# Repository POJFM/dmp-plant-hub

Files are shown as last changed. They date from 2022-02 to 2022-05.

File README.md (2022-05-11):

# 🌱 PlantHub

Ultra advanced smart irrigation system.

<div style="text-align: center;">
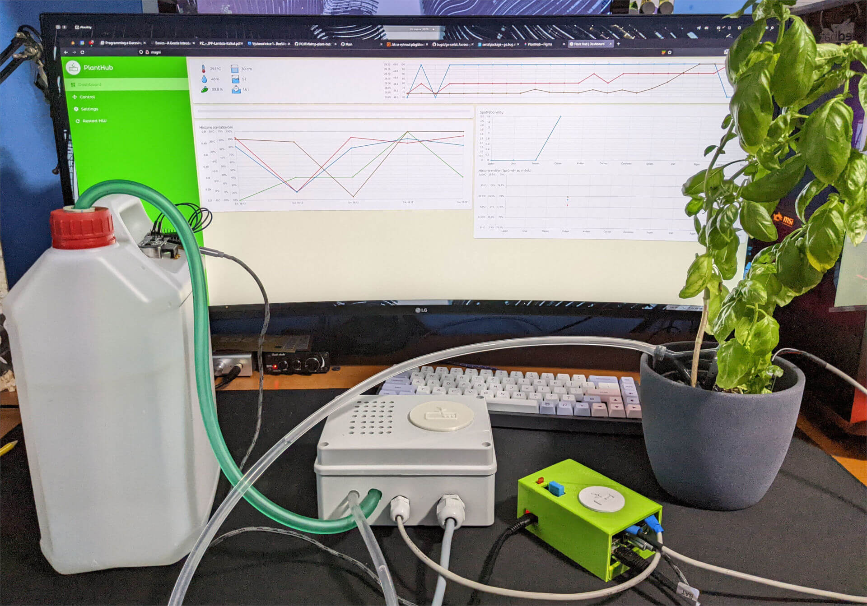
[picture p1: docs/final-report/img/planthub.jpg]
planthub
  
</div>

## 🍔 Tech stack

### 🖥️ Server and main app

- Chad GoLang
- Postgres DB :5420
- communication with HW modules/sensors via GPIO
- GraphQL API for DB data
- REST API for live data from sensors

### 🌿 Web app (client)

- React
- Tailwind
- Material UI
- [Design on Figma](https://www.figma.com/file/7gMKRPDOrkKOT5GKmOmfsu/PlantHub?node-id=0%3A1)

## 🔧 Setup on RPi

clone the repository

```bash
git clone git@github.com:POJFM/dmp-plant-hub.git
cd dmp-plant-hub
```

create server and docker `.env` files

```bash
# server .env
cp server/.env.example server/.env
# docker .env
cp docker.env.example docker.env
```

let docker do its thing

```bash
docker-compose up -d
```

## 📦 Build docker images for arm

create client `.env` file

```bash
cp client/.env.example client/.env
```

setup docker

```bash
# create bob the builder
docker buildx create --name bob
# switch to bob
docker buildx use bob
docker buildx inspect --bootstrap
docker login
docker buildx
```

build and push images or run `scripts/build-docker.sh`

```bash
# client image
docker buildx build --platform linux/amd64,linux/arm64,linux/arm/v7 -t tassilobalbo/planthub-client --push client/.
# server image
docker buildx build --platform linux/arm64,linux/arm/v7 -t tassilobalbo/planthub-server --push server/.
```

## 🏠 Setup local subnet

- Install dhcp package:
  `yay -Syu dhcpcd`
- Configure subnet in `/etc/dhcpd.conf`:

```
subnet 192.168.0.0 netmask 255.255.255.224 {
  range 192.168.0.10 192.168.0.20;
}
```

- Add your network card to subnet
  `sudo ip addr add 192.168.0.1/24 dev enp3s0`
- Restart dhcp daemon
  `systemctl restart dhcpd4`

## 📄 Compile XeLaTeX to pdf

1. Add `XeLaTeX` config in vscode

```
    "latex-workshop.latex.recipe.default": "latexmk (xelatex)",
    "latex-workshop.latex.tools": [
        {
            "name": "xelatexmk",
            "command": "latexmk",
            "args": [
                "-xelatex",
                "-outdir=out",
                "final-report.tex"
            ]
        },
        {
            "name": "latexmk",
            "command": "latexmk",
            "args": [
                "-xelatex",
                "-synctex=1",
                "-interaction=nonstopmode",
                "-file-line-error",
                "%DOC%"
            ]
        }
    ],
    "latex-workshop.latex.recipes": [
        {
            "name": "latexmk (xelatex)",
            "tools": [
                "xelatexmk"
            ]
        }
    ],
```

2. Download `Calibri.ttf` and put it in `~/.fonts`
3. Compile with `latexmk -xelatex -outdir=final-report ./final-report/final-report.tex`

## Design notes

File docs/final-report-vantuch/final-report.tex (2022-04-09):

\documentclass[12pt,a4paper]{article}
\usepackage[utf8]{inputenc}
\usepackage[sfdefault]{ClearSans}
\usepackage[T1]{fontenc}
\usepackage[left=35mm,right=20mm,top=25mm,bottom=25mm]{geometry}
\usepackage[czech]{babel}
\usepackage{titling}
\usepackage{graphicx}
\usepackage{caption}
\usepackage[list=true]{subcaption}
\usepackage{acronym}
\usepackage{setspace}
\usepackage{indentfirst}
\usepackage{hyperref}
\usepackage{listings}
\usepackage{tabularx}

\newcommand{\subtitle}[1]{%
	\posttitle{%
		\par\end{center}
		\begin{center}\large#1\end{center}
		\vskip0.5em}%
}

\newcommand*\wildcard[2][5cm]{\vspace*{2cm}\parbox{#1}{\centering\hrulefill\par#2\par}}

\graphicspath{ {./img/} }

%\onehalfspacing
\setlength{\parindent}{2em}
\setlength{\parskip}{0.1em}
\linespread{1.5}

\title{PlantHub}
\subtitle{MATURITNÍ ZKOUŠKA }
\author{Filip Sikora, Jakub Vantuch}
\date{}

\begin{document}

\begin{titlepage}
	\noindent
	%\vspace{0.1cm} \\
	\begin{center}
		\vspace*{0.2cm}
		\Huge\textbf{MATURITNÍ ZKOUŠKA}
		\vspace*{1cm} \\
		\large \emph{PRAKTICKÁ ZKOUŠKA Z ODBORNÝCH PŘEDMĚTŮ}
		\vspace*{1cm} \\
		\Large Téma č. 4 \\
		\vspace*{1cm}
		\Large Zavlažovací systém PlantHub \\
		\vspace*{1.3cm}
		%\vfill
		\normalsize
	\end{center}
	\begin{tabularx}{\textwidth}{l@{\hskip 0.5cm}XXl}
		Obor vzdělání:        & \multicolumn{3}{c}{\textbf{18 – 20 –
		M/01
		Informační technologie}}
		\\[10pt]
		Třída:                & \textbf{4. IT}
		                      &
		Autor práce:          & \textbf{Jakub Vantuch}
		\\[10pt]
		Školní rok:           & \textbf{2021/22}
		                      &
		Vedoucí učitel práce: &
		\textbf{Ing. Jiří Sumbal}
		\vspace*{2cm}
	\end{tabularx}
	„Prohlašuji, že jsem tuto práci vypracoval samostatně a použil jsem
	literárních
	pramenů a informací, které cituji a uvádím v seznamu použité literatury
	a
	dalších zdrojů informací.“

	\begin{tabularx}{\textwidth}{l@{\hskip 0.5cm}XXl}
		\\[10pt]
		V Frýdku-Místku, dne:             & \textbf{\dotfill}
		                                  &
		\textbf{\dotfill} & podpis
	\end{tabularx}
\end{titlepage}

\clearpage

\section*{Anotace}

PlantHub je automatický zavlažovací systém s \ac{WUI}.
Jádrem našeho systému je mikropočítač \ac{RPi} s procesorovou architekturou
\ac{ARM},
\ac{GPIO} a možností připojení pomocí ethernetu.
Vybrali jsme si jej, protože kombinuje malou velikost a vyšší výpočetní sílu
než Arduino. Musí totiž zvládnout řídit všechny senzory, ukládat data do
databáze a zároveň hostuje i samotnou webovou aplikaci. Systém PlantHub dále
získává informace o teplotě, vlhkosti a tlaku vzduchu a promítá je ve svém
\ac{WUI}. Ve stejné chvíli naměřená data ukládá do databáze v periodě 4
hodin. Jelikož voda časem z nádrže dojde systém PlantHub snímá stav hladiny
vody v nádrži a včas upozorní, že je třeba doplnit vodu.

\section*{Klíčová slova}

zavlažování; automatizace; statistika; živě; RaspberryPi; uživatelské rozhraní

\clearpage

\tableofcontents

\clearpage

\section{Úvod}

Mým cílem je návrh, sestavení a naprogramování automatického zavlažovacího
systému s názvem PlantHub. Systém se skládá z řídící jednotky (stanice),
senzorů, čerpadla, nádrže a \ac{WUI}. Tato stanice pravidelně snímá data ze
senzorů
měřících
teplotu a vlhkost vzduchu, vlhkost půdy a stav hladiny v nádrži, z té pak
stanice přečerpává vodu pomocí čerpadla spouštěného tranzistorem. Naměřená
data
se posílají živě pomocí \ac{REST} \ac{API} prostřednictvím
protokolu HTTP do \ac{WUI}. Samostně se poté v periodě čtyř hodin ukládají do
PostgreSQL databáze běžící v docker
containeru. Docker container si můžeme představit jako jednodušší a lépe
škálovatelnou verzi
virtualizace. Uložená data se vykreslí do
statistik
změn teploty a vlhkosti vzduchu, vlhkosti půdy a počtů zavlažování v časovém
rozsahu zobrazitelných v dashboardu \ac{WUI}. Pro načtení historických dat z
databáze
používáme \ac{GraphQL} \ac{API}, jelikož nabízí šetrnější přístup k datům,
vybráním pouze
těch záznamů z tabulky, které opravdu využíváme. V případě nedostupnosti
serveru by se ve \ac{WUI} měla pořád načítat živě naměřená data z \ac{REST}
\ac{API}. Přístup
k naměřeným datům a
\ac{WUI} má pouze
uživatel lokální
sítě, do které je planthub připojen pomocí ethernet kabelu. Pro správnou funkci
stanice je tedy zapotřebí router s přístupem k internetu a DHCP serverem.

Ve \ac{WUI} hostovaném na naší stanici, a sestavém pomocí javascriptového
frameworku
React.js, CSS frameworku
Tailwind a programovacího jazyku Typescript, který je supersetem javascriptu,
podporujícím volitelné statické typování, má uživatel
možnost zobrazení statistik jak živě naměřených dat tak dat historických v
nastavitelných grafech dashboardu. \ac{WUI} také nabízí manuální kontrolu nad
čerpadlem s časovačem začátku zavlažování a restartem hlavního programu.
Nastavitelné je jak \ac{WUI} tak i samotné faktory zavlažování jako je limit
vlhkosti
půdy, doba zavlažování nebo limit hladiny vody.

Jednotlivé součásti a moduly stanice jsme vybrali podle finanční dostupnosti a
adekvátních technických
požadavků na přesnost měření.
Zapojení těchto modulů do obvodu jsme prvně provedli ve webové aplikaci
EasyEDA, která nabízí jednoduché prostředky pro návrh technických
schémat. Tento obvod jsme poté v testovací verzi postavili na nepájivém
poli a ve finální verzi navrhli a objednali vlastní \ac{PCB}. Pro ochranu naší
stanice jsme v open-source programu FreeCad navrhli model krytu, který jsme
následně vytiskli na 3D tiskárně. Vymstila se nám však nepřesnost rozměrů krytu
a při vkládání stanice do krytu se nám podařilo zlomit SD kartu s operačním
systémem, daty a nasazenými programy. Po reinstalaci operačního systému jsme
opravili rozměry vytvořeného modelu krytu a
vytiskli kryt podruhé, tentokrát ve správných rozměrech.

Hlavní program jsme v prvotní verzi psali ve vysokoúrovňovém programovacím
jazyce Python, od kterého jsme nakonec upustili kvůli vysokým technickým
nárokům. Naše rozhodnutí nás nakonec dovedlo k jazyku
Go vytvořeného Googlem a určeného pro concurrency, rychlou kompilaci i průběh
programu, backend webových aplikací a mnoho
další funkcionality. Tento jazyk se nám zalíbil natolik že jsme se v něm
rozhodli
udělat jak \ac{API},
databázové funkce tak i hlavní program. Program je rozdělen na několik sekvencí
z toho hlavní jsou měřící sekvence kde se každou sekundu provádí měření dat ze
senzorů a následné odesílání na \ac{REST} \ac{API} webové aplikace a channely
vytvořené
pro komunikaci mezi go rutinama a sekvence controlleru, která pomocí snímání
dat z databáze určuje jestli se jedná o první spuštění PlantHubu, a podle toho
určí jestli se spustí incializační sekvence nebo sekvence zavlažování.

\clearpage

\section{Seznam zkratek a pojmů}

\begin{acronym}
	\acro{WUI}{Webové uživatelské rozhraní}
	\acro{API}{Application programming interface}
	\acro{REST}{Representaion programming interface}
	\acro{GraphQL}{Graph query languge}
	\acro{PCB}{Printed circuit board}
	\acro{RPi}{Raspberry Pi}
	\acro{CPU}{Central Processing Unit}
	\acro{ARM}{Advanced RISC Machines}
	\acro{GPIO}{General-purpose input/output}
	\acro{ADC}{Analogově digitální převodník}
	\acro{DHT11}{Digital humidity temperature v.11}
	\acro{HC-SR04}{Ultrasonický senzor vzdálenosti}
	\acro{LED}{Light Emitting Diode}
	\acro{SAR}{Successive-approximation}
	\acro{PETG}{Polyethylene terephthalate glycol filament}
	\acro{LSB}{Least significant bit}
	\acro{CLR}{Common Language Runtime}
	\acro{JVM}{Java virtual machine}
\end{acronym}

\clearpage

\section{Hardware}

Potřebujeme vyvinout vhodné pouzdro pro naše Raspberry, abychom ochránili
citlivé elektronické součástky a ve stejné chvíli měli možnost jednoduše
vyjmout stanici z krytu. Budeme ho tisknout na 3D tiskárně pevným \ac{PETG}
filamentem. K
zavlažování je potřeba postavit i nádrž na vodu, ze které bude naše čerpadlo
přečerpávat vodu k zavlažování, proto jsme se rozhodli pro nádobu s co
nejvetším objemem a postavili ji z upraveného 5L soudku.

\subsection{Senzory}

\subsubsection{Senzor teploty a vlhkosti vzduchu DHT11}

Senzor \ac{DHT11} se skládá z jednotky pro měření teploty, jednotky pro měření
vlhkosti a převodníku.

Teplotu měří senzor thermistorem. Thermistor je keramický polovodič, který
zmenšuje svou rezistivitu, když se okolní teplota zvýší.

Vlhkost měří senzor na základě rezistivity substrátu umístěného mezi dvěma
elektrodami. Tento substrát zachytává vlhkost a vytváří tak vodivé prostředí

\subsubsection{Senzor vlhkosti půdy}

Jedná se o kapacitní senzor, ten se skládá ze dvou vodivých desek a převodníku.
Čidlo funguje na způsob kapacitoru avšak jeho kapacita je ovlivněna vlhkostí,
která ovlivňuje dielektrikum mezi dvěma deskami.

\subsubsection{Analogově digitální převodník MCP3008}

\ac{RPi} má v rámci \ac{GPIO} pouze digitální vstupy, protože je ale senzor
vlhkosti půdy
analogový museli jsme použít \ac{ADC}. Přemapujeme tedy analogový
signál
do
osmi různých digitálních hodnot, kterým se také říká 3bitové rozlišení, to
definuje tu nejmenší hodnotu změny, který převodník dokáže rozlišit, této
hodnotě se říká \ac{LSB}. \ac{ADC} poté pomocí \ac{SAR}
definuje adresu v binárním podání srozumitelným pro digitální vstup.

% \begin{figure}[h]
% 	\centering
% 	\includegraphics[width=8cm]{sar_adc.png}
% 	\caption{\ac{SAR}}
% \end{figure}

\subsubsection{Ultrasonický senzor HC-SR04}

\ac{HC-SR04} vydává zvukové vibrace na vysoké frekvenci, neslyšitelné pro
lidské
ucho. Poté čeká, až se zvuk odrazí zpět, a vypočítá vzdálenost na základě času
měřeného od vysílání zvukové vlny k zpětnému přijmutí

Všechny naměřené údaje jsou v převodníku senzoru přepočítány na jednotky dané
veličiny a odeslány analogovým signálem do řídící jednotky.

\subsubsection{Čerpadlo}

Naše zvolené ponorné mini čerpadlo eses se skládá z DC motoru, na němž je
upevněna centrifuga pro
čerpání vody a vlastního pouzdra, z kterého vede otvor pro napojení odtokové
hadičky. Čerpadlo je připojeno na zdroj napětí 5V a zem.

\subsubsection{Tranzistor 2N2222}

Protože samotný signální pin neposkytuje dostatečné napětí pro chod čerpadla
ovládáme jej tranzistorem 2N2222. Tento tranzistor je bipolární
Negative-Positive-Negative tranzistor, to znamená že jeho polarita je nastavená
tak aby na kolektoru přijímal pozitivní napětí. Díky našemu vyměnitelnému
připojení modulů je
možné čerpadlo vyměnit a přívodný kabel používat jako spouštěč čerpadla
jakéhokoliv výkonu a nároků na zdroj.

\subsection{Architektura ARM}

\ac{ARM} je nejnovější \ac{CPU} architektura. Využívají ji všechny moderní
chytré
telefony, zařízení s operačním systémem Android i Apple produkty. Dnes už mají
\ac{ARM} procesory zařízení s Windows nebo MacOS.\@

% \ac{ARM} je založen na RISC (Reduced Instruction Set Computing), tyto procesory jsou designované na 

\clearpage

\section{Návrh obvodu a plošného spoje}

Testovací verzi našeho obvodu jsme postavili na nepájivém kontaktním poli,
které jsme používali pouze v testovací verzi. Jakmile jsme měli vše plně
odzkoušeno a plně otestováno přešli jsme na profesionálnější řešení.
Což tedy v druhé fázi znamenalo sestrojit a nechat vytisknout náš vlastní obvod
přepracovaného schématu \ac{PCB} a vytisknutého společnosti JLCPCB na naše
vlastní
náklady.

\begin{figure}[h]
	\centering
	\begin{subfigure}[b]{0.4\linewidth}
		
		\caption{Diagram \ac{PCB}}
	\end{subfigure}
	\begin{subfigure}[b]{0.4\linewidth}
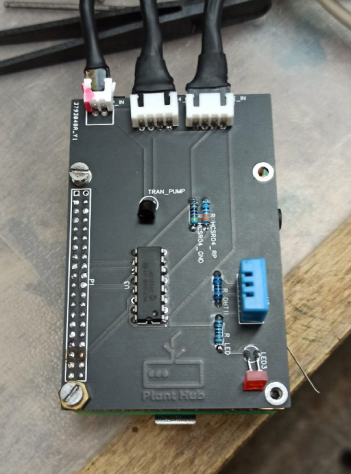
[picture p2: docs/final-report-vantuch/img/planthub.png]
		
		\caption{PlantHub \ac{PCB} se senzory}
	\end{subfigure}
	\caption{}
\end{figure}

\clearpage

\section{Fyzická realizace}

% předělat na fotku celého planthubu

\begin{figure}[h]
	\centering
	
	\caption{Fyzická realizace}
\end{figure}

\clearpage

\section{Hlavní program}

\subsection{Postup práce}

Náš hlavní program pro zavlažování a komunikaci s databází a \ac{WUI}
jsme začali psát ve vysokoúrovňovém programovacím jazyce Python. Od toho jsme
ale nakonec upustili kvůli horší výkonu, a tak jsme program přepsali v
programovacím jazyku Go.

\begin{figure}[h]
	\centering
	
	\caption{Vývojový diagram programu}
\end{figure}

\subsection{Fáze programu}

Fáze programu se spouštějí buďto v samostatné go rutině a komunikují spolu
pomocí channelů nebo na základě podmínek kde se po splnění požadavků ukončí.

\subsubsection{Měření}

Senzor vlhkosti půdy a \ac{DHT11} průběžně posílají naměřená data do \ac{RPi},
kde se
ukládají do databáze. Jestliže naměřené hodnoty překročí limitní hodnoty,
\ac{RPi}
pošle signál pro otevření tranzistoru což spustí čerpadlo.

\subsubsection{Periodické ukládání dat}

V samostatné rutině běží funkce pro ukládání naměřených dat v periodě 4 hodin.
Naměřená data jsou následně statisticky zobrazena v \ac{WUI}.

\subsubsection{Controller}

Po spuštění měřící sekvence a sekvence periodického ukládání dat se spustí
buďto incializační sekvence a nebo zavlažovací sekvence podle toho jestli jsou
v databázi data nastavení, nastavovaná ve \ac{WUI}. Pokud data nejsou tak
program
čeká na uložení dat z \ac{WUI} a \ac{LED} dioda bliká dvakrát po sobě dokud
data
nejsou
dostupná, pokud ano spustí se zavlažovací sekvence, načtou se limitní data z
databáze a v periodě 1 sekundy se budou číst data o vlhkosti půdy.

\subsubsection{Inicializace}

Půda musí být ze začátku suchá. Senzor vlhkosti půdy zasuneme co nejhlouběji do
půdy. \ac{RPi} bude chvíli sbírat data a pak je zprůměruje do hodnoty, která
bude
sloužit jako limit pro spuštění čerpadla.

V \ac{WUI} jde navíc ještě manuálně nastavit hranice vlhkosti půdy pro spuštění
čerpadla.

Nastavit se dá také množství vody, které bude přečerpáno při jednom spuštění a
jaká je hranice pro přijatelnou výšku hladiny vody v nádrži. Pokud nejsou tyto
hodnoty uvedeny čerpadlo bude vodu přečerpávat, dokud se nezmění hodnota
kapacitního čidla pro měření vlhkosti půdy a \ac{HC-SR04} použije výchozí
nastavení.

\subsubsection{Zavlažování}

Čerpadlo začne čerpat vodu a zavlažovat rostlinu. Voda se čerpá tak dlouho,
dokud senzor vlhkosti půdy nezmění svou hodnotu nebo dokud není vyčerpán limit
přečerpané vody na jedno spuštění.

\subsubsection{Kontrola}

Po ukončení přečerpávání se spustí \ac{HC-SR04} a změří výšku hladiny vody.
Naměřená
data poté odešle do \ac{RPi} kde se uloží do databáze. Pokud bude naměřená
hodnota
nižší, než je limitní hodnota, začne blikat \ac{LED} a \ac{RPi} odešle
upozornění o
doplnění nádrže do \ac{WUI}. Jakmile bude hladina doplněna, signalizace se
vypne.

\subsubsection{Ukládání dat}

Náš systém ukládá zvlášť periodicky naměřená data a data naměřená před
zavlažováním, dále ukládá nastavení jak pro limity k zavlažování, tak pro
\ac{WUI}.

\subsection{Go}

Go je open-source programovací jazyk, který byl vytvořen společností Google v
roce 2009. Je to stále relativně nový programovací jazyk, který se nevyvinul z
jiných jazyků jako C\# a Java. Go ignoruje teorii o programovacích jazycích.
Místo toho aby se zaměřoval na akademické teorie, se zaměřuje na reálné
praktiky používané pro vývoj next-gen v cloudových, distribuovaných a
souběžných aplikacích.

Jazyk Go je staticky typovaný a využívá garbage collector, jedná se o
kompilovaný programovací jazyk, který své binární soubory kompiluje pro každou
platformu. Dá se zařadit do skupiny C jazyků na základě jeho základního
syntaxe. Go poskytuje expresivní syntax s jednoduchým typovým systémem a má
vestavěné nástroje pro paralelní programování. Výkon Go je srovnatelný s jazyky
C a C++, ale zároveň nabízí rychlý a jednoduchý vývoj aplikací.

Stejně jako C a C++ se Go kompiluje do nativního strojového kódu, takže
nepotřebujeme běhové prostředí jako \ac{CLR} a \ac{JVM}. To má řadu výhod,
třeba při
distribuci aplikace v aplikačních kontejnerech jako je Docker.

\subsubsection{Paralelní programování v Go}

Vývoj počítačů se značně posunul v průběhu posledního desetiletí. V minulosti
aplikace běžely na počítačích pouze s jediným procesorovým jádrem. Dnes je
standardní vidět čtyř-jádrové procesory v uživatelských počítačích, dokonce i
naše Raspberry má dvě jádra. Stále ale používáme programovací jazyky a
technologie navržené v éře, kdy byly dostupné pouze jednojádrové procesory.

Většina programovacích jazyků dnes nabízí knihovny nebo frameworky pro
paralelní programování, ale nemají tuto vlastnost zbudovanou přímo v jádře
jazyka. V Go je paralelní programování součástí jazyka už od samotného počátku.
Používá takzvané Gorutiny, které umožňují spouštět funkce souběžně. Souběžné
funkce pak mezi sebou mohou komunikovat a předávat data pomocí kanálů. Dokonce
i některé standardní knihovny jazyka mají zabudovanou souběžnost. Například
standardní knihovna `net/http' pro programování HTTP zpracovává přicházející
požadavky souběžně pomocí Gorutin.

\subsubsection{Typový systém}

Pragmatický design Go neobsahuje klíčové slovo pro třídu a jeho objektová
orientace je odlišná od tradičních objektově orientovaných programovacích
jazyků. V Go nahrazuje funkci tradiční třídy typ struct. Dědění není v go
podporováno, ale podporuje kompozici typů.

Zde je příklad, který demonstruje typový systém Go spolu s rozhraním
(interface), typem struct a vnořením pro typovou kompozici.

%Ukázka typového systému

\clearpage

\section{Interaktivní ovládání z WUI}

\clearpage

\section{Závěr}

Náš projekt je stále ve vývoji a mnoho z kritických funkcí projektu není ještě
dokončeno. S vývojem dále pokračujeme, protože se jedná o naši maturitní práci.
Myslíme si, ale že tento projekt má v budoucnu potenciál stát se úspěšným
startupem, takže plánujeme pokračovat ve vývoji i po maturitě.

Tato práce byla pro nás velkým přínosem, naučili jsme se mnoho nových
dovedností a načerpali nové informace.

% Budoucí plány

\clearpage

\section{Použité zdroje}

\begin{itemize}
	\item \href{http://www.latex-tutorial.com}{LaTeX-Tutorial}.
	\item \href{http://www.freecodecamp.org}{Free Code Camp}.
	\item \href{http://www.go.dev}{Go lang}.
	\item \href{http://www.reactjs.org}{React.js}.
	\item \href{http://www.tailwindcss.com}{Tailwind CSS}.
	\item \href{http://www.typescriptlang.org}{Typescript}.
	\item \href{https://www.kali.org/tools/code-oss}{Code-OSS}.
	\item \href{https://www.jetbrains.com/go/}{Goland}.
	\item \href{https://git-scm.com/}{Git}.
	\item \href{https://www.figma.com/}{Figma}.
	\item \href{https://www.freecadweb.org/}{FreeCad}.
	\item

	      \href{https://componentsearchengine.com/library/easyeda}{EasyEDA}.
\end{itemize}

\section{Seznam příloh}

\begin{itemize}
	\item \href{https://github.com/POJFM/dmp-plant-hub}{Zdrojový kód na
		      github.com}
	\item Prezentace
	\item

	      \href{https://www.youtube.com/watch?v=oo2_pDX5OE4}{Videoprezentace}
\end{itemize}

\end{document}

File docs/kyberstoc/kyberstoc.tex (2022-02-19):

\documentclass[11pt,a4paper]{article}
\usepackage[utf8]{inputenc}
\usepackage[sfdefault]{ClearSans}
\usepackage[T1]{fontenc}
\usepackage[left=25mm,right=25mm,top=25mm,bottom=25mm]{geometry}
\usepackage[czech]{babel}
\usepackage{titling}
\usepackage{graphicx}
\usepackage{caption}
\usepackage{subcaption}
\usepackage{acronym}
\usepackage{setspace}
\usepackage{indentfirst}

\newcommand{\subtitle}[1]{%
  \posttitle{%
    \par\end{center}
    \begin{center}\large#1\end{center}
    \vskip0.5em}%
}

\graphicspath{ {./img/} }

\onehalfspacing
\setlength{\parindent}{2em}
\setlength{\parskip}{0.1em}

\title{PlantHub}
\subtitle{soutěž KYBER STOČ 2022 }
\author{Filip Sikora, Jakub Vantuch}
\date{}

\begin{document}

\begin{titlepage}
	\noindent
	\vspace{4cm} \\
	\begin{center}
		\Huge\textbf{PlantHub}
		\vspace*{1cm} \\
		\LARGE Filip Sikora, Jakub Vantuch
		\vspace*{1cm} \\
		\Large soutěž KYBER STOČ 2022
		\vfill
		\normalsize
		\begin{minipage}{0.7\linewidth}
			Třída: \textbf{4.IT}
		\end{minipage}%
		\begin{minipage}{0.25\linewidth}
			Školní rok: \textbf{2021/22}
		\end{minipage}
	\end{center}
	
\end{titlepage}

%\begin{titlingpage}
%	\maketitle
%	\begin{minipage}{0.7\linewidth}
%		Třída: \textbf{4.IT}
%	\end{minipage}%
%	\begin{minipage}{0.25\linewidth}
%		Školní rok: \textbf{2021/22}
%	\end{minipage}
%\end{titlingpage}

\section*{Úvod}

PlantHub je automatický zavlažovací systém s webovým uživatelským rozhraním. Jádrem našeho systému je mikropočítač RPi s procesorovou architekturu ARM. Vybrali jsme si jej, protože kombinuje malou velikost a vyšší výpočetní sílu než Arduino. Musí totiž zvládnout řídit všechny senzory, ukládat data do databáze a zároveň hostuje i samotnou webovou aplikaci. Systém PlantHub dále získává informace o teplotě, vlhkosti a tlaku vzduchu a promítá je ve svém webovém rozhraní. Ve stejné chvíli naměřená data ukládá do databáze v periodě 4 hodin. Jelikož voda časem z nádrže dojde systém PlantHub snímá stav hladiny vody v nádrži a včas upozorní, že je třeba doplnit vodu.

\section*{Hardware}

Potřebujeme vyvinout vhodné pouzdro pro naše Raspberry, abychom ochránili citlivé elektronické součástky. Budeme ho tisknout na 3D tiskárně. K zavlažování je potřeba vyvinout i nádrž na vodu ze kterého bude čerpat naše čerpadlo.

\subsubsection*{DHT11}

Senzor DHT11 se skládá z jednotky pro měření teploty, jednotky pro měření vlhkosti a převodníku.

Teplotu měří senzor termistorem. Thermistor je keramický polovodič, který zmenšuje svou rezistivitu, když se okolní teplota zvýší.

Vlhkost měří senzor na základě rezistivity substrátu umístěného mezi dvěma elektrodami. Tento substrát zachytává vlhkost a vytváří tak vodivé prostředí

\subsubsection*{Senzor vlhkosti půdy}

Jedná se o kapacitní senzor, ten se skládá ze dvou vodivých desek a převodníku. Čidlo funguje na způsob kapacitoru avšak jeho kapacita je ovlivněna vlhkostí, která ovlivňuje dielektrikum mezi dvěma deskami.

\subsubsection*{MCP3008}

RPi má v rámci GPIO pouze digitální vstupy, protože je ale senzor vlhkosti půdy analogový museli jsme použít ADC převodník.

\subsubsection*{HC-SR04}

HC-SR04 vydává zvukové vibrace na vysoké frekvenci, neslyšitelné pro lidské ucho. Poté čeká, až se zvuk odrazí zpět, a vypočítá vzdálenost na základě času měřeného od vysílání zvukové vlny k zpětnému přijmutí

Všechny naměřené údaje jsou v převodníku senzoru přepočítány na jednotky dané veličiny a odeslány analogovým signálem do řídící jednotky.

\subsubsection*{Čerpadlo}

Naše zvolené čerpadlo se skládá z DC motoru, na němž je upevněna centrifuga pro čerpání vody a vlastního pouzdra, z kterého vede otvor pro napojení odtokové hadičky.

\subsubsection*{2N2222}

Protože samotný signální pin neposkytuje dostatečné napětí pro chod čerpadla ovládáme jej NPN tranzistorem.

\section*{Obvod}

Testovací verzi našeho obvodu jsme postavili na nepájivém kontaktním poli, které jsme používali dokud jsme neměli plně otestovanou funkcionalitu hardwaru. V druhé fázi jsme náš obvod přepracovali do schématu PCB a nechali jej vytisknout.

\begin{figure}[h]
	\centering
	\begin{subfigure}[b]{0.4\linewidth}
		
		\caption*{Diagram PCB}
	\end{subfigure}
	\begin{subfigure}[b]{0.4\linewidth}
		
		\caption*{PlantHub PCB se senzory}
	\end{subfigure}
\end{figure}

\clearpage

\section*{Hlavní program}

\subsection*{Postup práce}

Náš hlavní program pro zavlažování a komunikaci s databází a webovým rozhraním jsme začali psát ve vysokoúrovňovém programovacím jazyce Python. Od toho jsme ale nakonec upustili kvůli pomalejšímu průběhu programu, proto jsme přešli na programovací jazyk GO.

\begin{figure}[h]
	\centering
	
	\caption*{Vývojový diagram programu}
\end{figure}

\subsection*{Fáze programu}

\subsubsection*{Inicializace}

Půda musí být ze začátku suchá. Senzor vlhkosti půdy zasuneme co nejhlouběji do půdy. Rpi bude chvíli sbírat data a pak je zprůměruje do hodnoty, která bude sloužit jako limit pro spuštění čerpadla.

V UI jde navíc ještě manuálně nastavit hranice vlhkosti půdy pro spuštění čerpadla.

Nastavit se dá také množství vody, které bude přečerpáno při jednom spuštění a jaká je hranice pro přijatelnou výšku hladiny vody v nádrži. Pokud nejsou tyto hodnoty uvedeny čerpadlo bude vodu přečerpávat, dokud se nezmění hodnota kapacitního čidla pro měření vlhkosti půdy a HC-SR04 použije výchozí nastavení.

\subsubsection*{Měření}

Senzor vlhkosti půdy a DHT11 průběžně posílají naměřená data do Rpi, kde se ukládají do databáze. Jestliže naměřené hodnoty překročí limitní hodnoty, Rpi pošle signál pro otevření tranzistoru což spustí čerpadlo

\subsubsection*{Zavlažování}

Čerpadlo začne čerpat vodu a zavlažovat rostlinu. Voda se čerpá tak dlouho, dokud senzor vlhkosti půdy nezmění svou hodnotu nebo dokud není vyčerpán limit přečerpané vody na jedno spuštění.

\subsubsection*{Kontrola}

Po ukončení přečerpávání se spustí HC-SR04 a změří výšku hladiny vody. Naměřená data poté odešle do Rpi kde se uloží do databáze. Pokud bude naměřená hodnota nižší, než je limitní hodnota, začne blikat LED dioda a Rpi odešle upozornění o doplnění nádrže do UI. Jakmile bude hladina doplněna, signalizace se vypne.

\subsubsection*{Periodické ukládání dat}

V samostatné rutině běží funkce pro ukládání naměřených dat v periodě 4 hodin. Naměřená data jsou následně statisticky zobrazena v UI.

\subsubsection*{Ukládání dat}

Náš systém ukládá zvlášť periodicky naměřená data a data naměřená před zavlažováním, dále ukládá nastavení jak pro limity k zavlažování, tak pro webové rozhraní.

\section*{Webové rozhraní}

Webovovou aplikaci jsme napsali v JavaScriptovém frameworku React.js a css frameworku Tailwind. Ve webovém rozhraní je možné zobrazit si statisky jak živě naměřených dat, tak dat uložených v databázi. Z OpenWeather API získáváme data o předpovědi počasí.

\begin{figure}[h]
	\centering
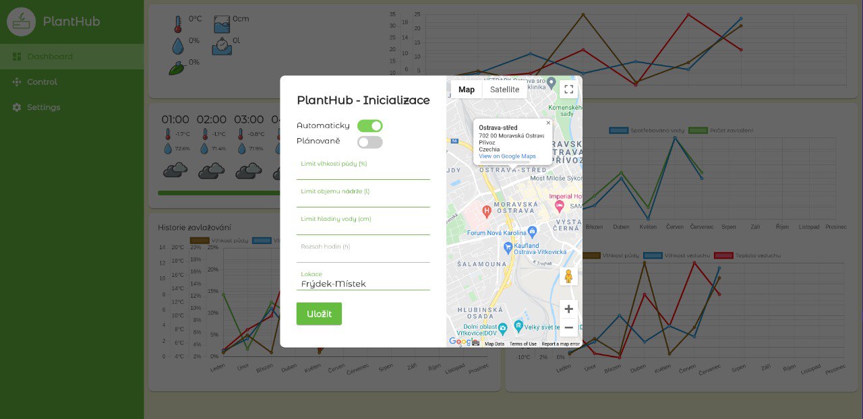
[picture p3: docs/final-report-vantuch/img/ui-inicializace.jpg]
	
	\caption*{Okno prvotního nastavení. Nastaví se zde limity a celkové nastavení aplikace.}
\end{figure}

\begin{figure}[h]
	\centering
	
	\caption*{Uživatelské rozhraní}
\end{figure}

\begin{figure}[h]
	\centering
	
	\caption*{Interaktivní ovládání celého systému lze provést v již zmiňované webové aplikaci. Dovoluje uživateli kdykoliv spustit čerpadlo na zalévání rostliny.}
\end{figure}

\begin{figure}[h]
	\centering
	
	\caption*{V nastavení se dá změnit nastavení aplikace i limitů pro zavlažování. Nastavení se poté uloží do databáze.}
\end{figure}

\clearpage

\section*{Databáze}

Pro databázi jsme se rozhodli použít databázový systém PostgreSQL. Jak vyplývá z názvu, jedná se o SQL databázi, ty jsou vhodné pro ukládání velkého objemu dat, jako právě data z našich senzorů. Webová aplikace používá pro přístup k datům z databáze GraphQL API.

GraphQL je query, který je konkurent řešení REST API. Nabízí efektivnější tvorbu API a také umožňuje efektivnější přístup k datům z databáze. Umožňuje vybrat pouze data, která momentálně aplikace používá a dovoluje vynechat data, která zrovna potřebné nejsou.

\section*{Webový server}

Web server jsme napsali v moderním jazyku Go, který nyní roste v popularitě hlavně mezi cloudovými vývojáři a v oblasti vývoje microservices. Dokáže se exekuční rychlostí přiblížit k nízkoúrovňovým jazykům jako je C nebo Rust, ale zároveň zůstává velmi lidsky čitelný a jednoduchý na použití. Na rozdíl od jazyků jako C a Rust má například garbage collector.

\section*{Na čem ještě pracujeme}

\begin{itemize}
  \item RPi case z 3D tisku
  \item Celková funkcionalita hlavního programu a jeho sekvencí
  \item Realizace nádrže pro vodu
\end{itemize}

\begin{figure}[h]
	\centering
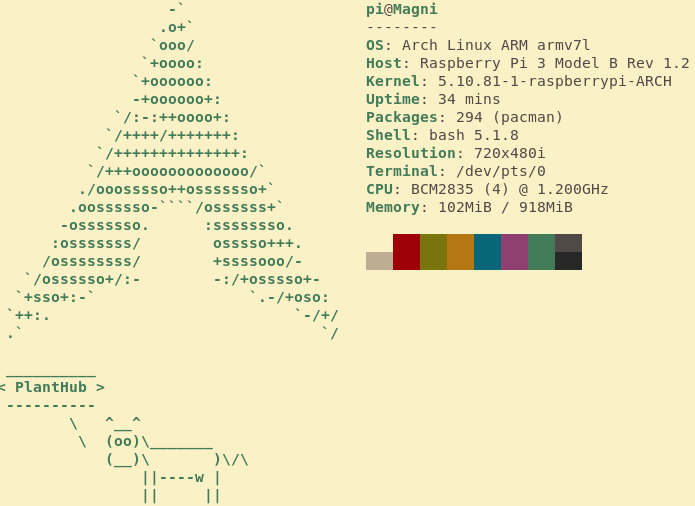
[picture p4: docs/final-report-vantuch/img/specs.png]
	
	\caption*{Specifikace RaspberryPi}
\end{figure}

\clearpage

\section*{Seznam zkratek a pojmů}

\begin{acronym}
	\acro{API}{Application programming interface}
	\acro{REST}{Representaion programming interface}
	\acro{GraphQL}{Graph query languge}
	\acro{PCB}{Printed circuit board}
	\acro{RPi}{Raspberry Pi}
	\acro{ARM}{Advanced RISC Machines}
	\acro{GPIO}{General-purpose input/output}
	\acro{DHT11}{Digital humidity temperature (sensor) v.11}
	\acro{HC-SR04}{ltrasonický senzor vzdálenosti}
	\acro{MCP3008}{Analog-digital converter}
	\acro{Cerpadlo}{Ponorné mini čerpadlo eses}
	\acro{2N2222}{NPN tranzitor}
	\acro{SPI}{Serial peripheral interface}
\end{acronym}

\end{document}

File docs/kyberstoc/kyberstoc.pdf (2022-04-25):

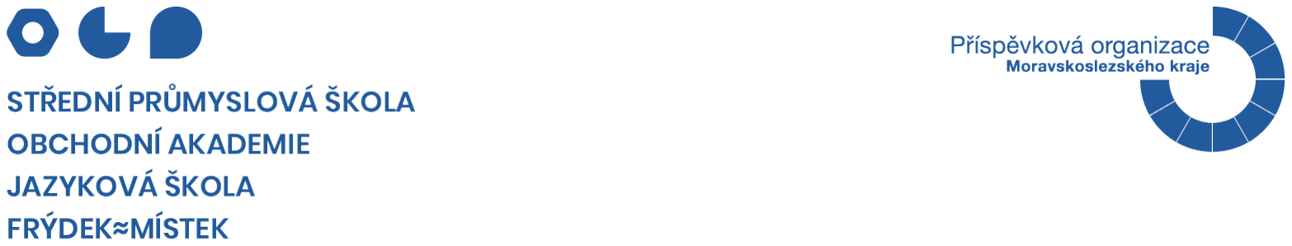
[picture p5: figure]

# PlantHub

## Filip Sikora, Jakub Vantuch

## soutěž KYBER STOČ 2022

Třída: 4.IT | Školní rok: 2021/22

## Úvod

PlantHub je automatický zavlažovací systém s webovým uživatelským rozhraním. Jádrem našeho systému je mikropočítač RPi s procesorovou architekturu ARM. Vybrali jsme si jej, protože kombinuje malou velikost a vyšší výpočetní sílu než Arduino. Musí totiž zvládnout řídit všechny senzory, ukládat data do databáze a zároveň hostuje i samotnou webovou aplikaci. Systém PlantHub dále získává informace o teplotě, vlhkosti a tlaku vzduchu a promítá je ve svém webovém rozhraní. Ve stejné chvíli naměřená data ukládá do databáze v periodě 4 hodin. Jelikož voda časem z nádrže dojde systém PlantHub snímá stav hladiny vody v nádrži a včas upozorní, že je třeba doplnit vodu.

## Hardware

Potřebujeme vyvinout vhodné pouzdro pro naše Raspberry, abychom ochránili citlivé elektronické součástky. Budeme ho tisknout na 3D tiskárně. K zavlažování je potřeba vyvinout i nádrž na vodu ze kterého bude čerpat naše čerpadlo.

DHT11

Senzor DHT11 se skládá z jednotky pro měření teploty, jednotky pro měření vlhkosti a převodníku.

Teplotu měří senzor termistorem. Thermistor je keramický polovodič, který zmenšuje svou rezistivitu, když se okolní teplota zvýší.

Vlhkost měří senzor na základě rezistivity substrátu umístěného mezi dvěma elektrodami. Tento substrát zachytává vlhkost a vytváří tak vodivé prostředí

Senzor vlhkosti půdy

Jedná se o kapacitní senzor, ten se skládá ze dvou vodivých desek a převodníku. Čidlo

funguje na způsob kapacitoru avšak jeho kapacita je ovlivněna vlhkostí, která ovlivňuje dielektrikum mezi dvěma deskami.

MCP3008

RPi má v rámci GPIO pouze digitální vstupy, protože je ale senzor vlhkosti půdy analogový museli jsme použít ADC převodník.

HC-SR04

HC-SR04 vydává zvukové vibrace na vysoké frekvenci, neslyšitelné pro lidské ucho. Poté čeká, až se zvuk odrazí zpět, a vypočítá vzdálenost na základě času měřeného od vysílání zvukové vlny k zpětnému přijmutí

Všechny naměřené údaje jsou v převodníku senzoru přepočítány na jednotky dané veličiny a odeslány analogovým signálem do řídící jednotky.

Čerpadlo

Naše zvolené čerpadlo se skládá z DC motoru, na němž je upevněna centrifuga pro čerpání vody a vlastního pouzdra, z kterého vede otvor pro napojení odtokové hadičky.

2N2222

Protože samotný signální pin neposkytuje dostatečné napětí pro chod čerpadla ovládáme

jej NPN tranzistorem.

## Obvod

Testovací verzi našeho obvodu jsme postavili na nepájivém kontaktním poli, které jsme používali dokud jsme neměli plně otestovanou funkcionalitu hardwaru. V druhé fázi jsme náš obvod přepracovali do schématu PCB a nechali jej vytisknout.

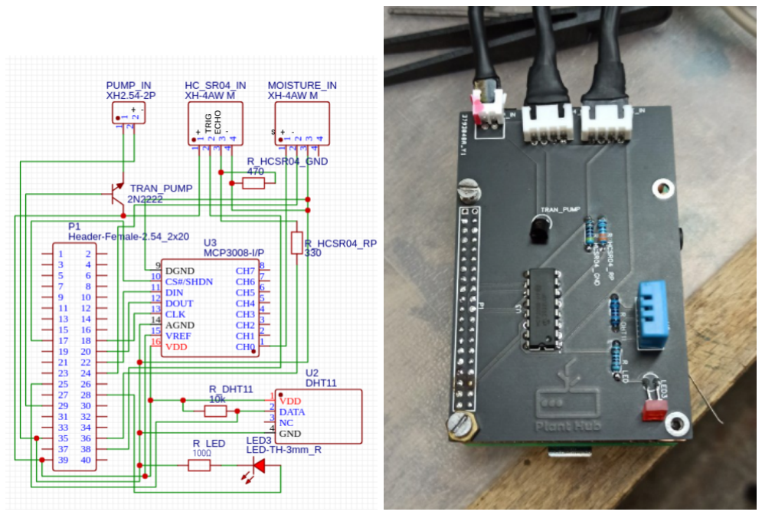
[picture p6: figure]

Diagram PCB | PlantHub PCB se senzory

## Hlavní program

Postup práce

Náš hlavní program pro zavlažování a komunikaci s databází a webovým rozhraním jsme začali psát ve vysokoúrovňovém programovacím jazyce Python. Od toho jsme ale nakonec upustili kvůli pomalejšímu průběhu programu, proto jsme přešli na programovací jazyk GO.

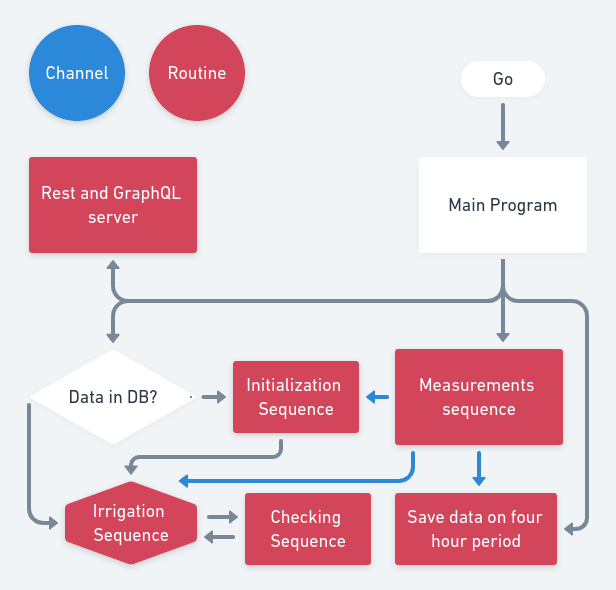
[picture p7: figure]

Vývojový diagram programu

Fáze programu

Inicializace

Půda musí být ze začátku suchá. Senzor vlhkosti půdy zasuneme co nejhlouběji do půdy. Rpi bude chvíli sbírat data a pak je zprůměruje do hodnoty, která bude sloužit jako limit pro spuštění čerpadla.

V UI jde navíc ještě manuálně nastavit hranice vlhkosti půdy pro spuštění čerpadla.

Nastavit se dá také množství vody, které bude přečerpáno při jednom spuštění a jaká je hranice pro přijatelnou výšku hladiny vody v nádrži. Pokud nejsou tyto hodnoty uvedeny čerpadlo bude vodu přečerpávat, dokud se nezmění hodnota kapacitního čidla pro měření vlhkosti půdy a HC-SR04 použije výchozí nastavení.

Měření

Senzor vlhkosti půdy a DHT11 průběžně posílají naměřená data do Rpi, kde se ukládají do databáze. Jestliže naměřené hodnoty překročí limitní hodnoty, Rpi pošle signál pro otevření tranzistoru což spustí čerpadlo

Zavlažování

Čerpadlo začne čerpat vodu a zavlažovat rostlinu. Voda se čerpá tak dlouho, dokud senzor

vlhkosti půdy nezmění svou hodnotu nebo dokud není vyčerpán limit přečerpané vody na jedno spuštění.

Kontrola

Po ukončení přečerpávání se spustí HC-SR04 a změří výšku hladiny vody. Naměřená data poté odešle do Rpi kde se uloží do databáze. Pokud bude naměřená hodnota nižší, než je limitní hodnota, začne blikat LED dioda a Rpi odešle upozornění o doplnění nádrže do UI. Jakmile bude hladina doplněna, signalizace se vypne.

Periodické ukládání dat

V samostatné rutině běží funkce pro ukládání naměřených dat v periodě 4 hodin. Naměřená data jsou následně statisticky zobrazena v UI.

Ukládání dat

Náš systém ukládá zvlášť periodicky naměřená data a data naměřená před zavlažováním, dále ukládá nastavení jak pro limity k zavlažování, tak pro webové rozhraní.

## Webové rozhraní

Webovovou aplikaci jsme napsali v JavaScriptovém frameworku React.js a css frameworku Tailwind. Ve webovém rozhraní je možné zobrazit si statisky jak živě naměřených dat, tak dat uložených v databázi. Z OpenWeather API získáváme data o předpovědi počasí.


Okno prvotního nastavení. Nastaví se zde limity a celkové nastavení aplikace.

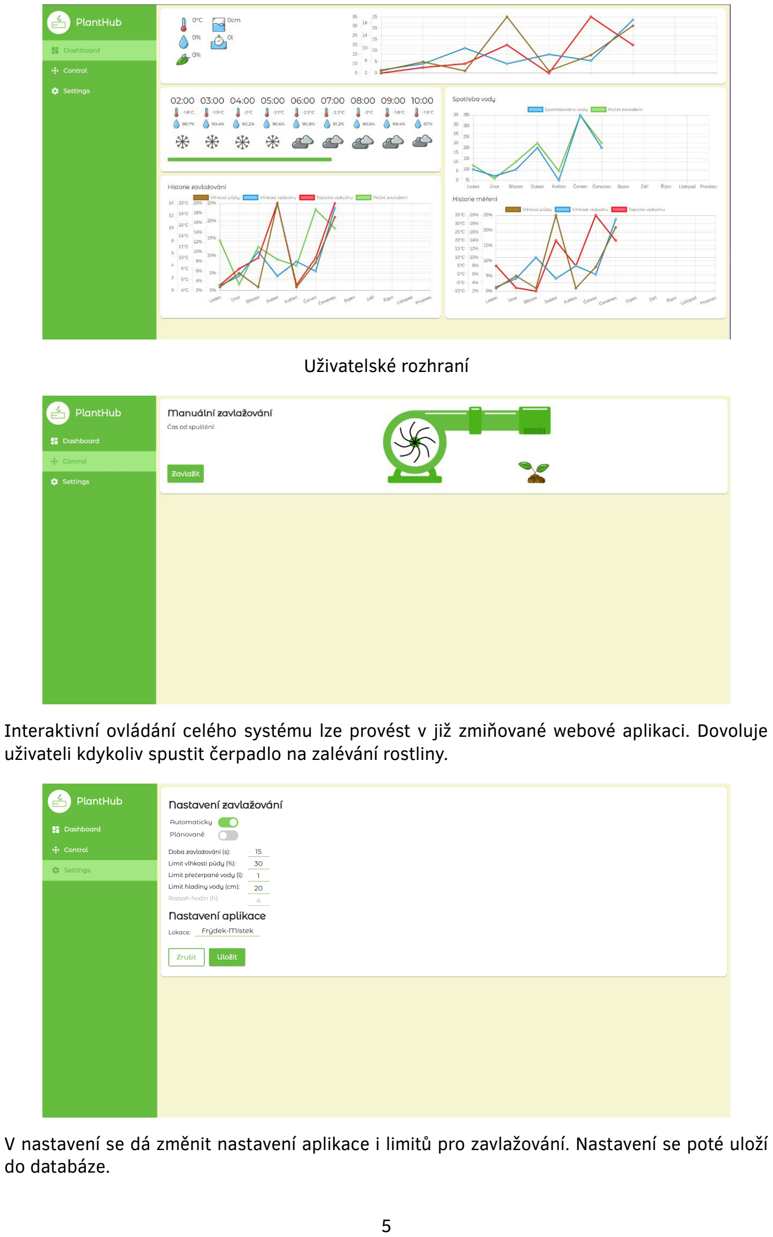
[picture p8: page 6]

Uživatelské rozhraní

Interaktivní ovládání celého systému lze provést v již zmiňované webové aplikaci. Dovoluje uživateli kdykoliv spustit čerpadlo na zalévání rostliny.

V nastavení se dá změnit nastavení aplikace i limitů pro zavlažování. Nastavení se poté uloží do databáze.

## Databáze

Pro databázi jsme se rozhodli použít databázový systém PostgreSQL. Jak vyplývá z názvu, jedná se o SQL databázi, ty jsou vhodné pro ukládání velkého objemu dat, jako právě data z našich senzorů. Webová aplikace používá pro přístup k datům z databáze GraphQL API.

GraphQL je query, který je konkurent řešení REST API. Nabízí efektivnější tvorbu API a také umožňuje efektivnější přístup k datům z databáze. Umožňuje vybrat pouze data, která momentálně aplikace používá a dovoluje vynechat data, která zrovna potřebné nejsou.

## Webový server

Web server jsme napsali v moderním jazyku Go, který nyní roste v popularitě hlavně mezi cloudovými vývojáři a v oblasti vývoje microservices. Dokáže se exekuční rychlostí přiblížit k nízkoúrovňovým jazykům jako je C nebo Rust, ale zároveň zůstává velmi lidsky čitelný a jednoduchý na použití. Na rozdíl od jazyků jako C a Rust má například garbage collector.

## Na čem ještě pracujeme

- RPi case z 3D tisku
- Celková funkcionalita hlavního programu a jeho sekvencí
- Realizace nádrže pro vodu


Specifikace RaspberryPi

## Seznam zkratek a pojmů

API Application programming interface

REST Representaion programming interface

GraphQL Graph query languge

PCB Printed circuit board

RPi Raspberry Pi

ARM Advanced RISC Machines

GPIO General-purpose input/output

DHT11 Digital humidity temperature (sensor) v.11

HC-SR04 ltrasonický senzor vzdálenosti

MCP3008 Analog-digital converter

Cerpadlo Ponorné mini čerpadlo eses

2N2222 NPN tranzitor

SPI Serial peripheral interface

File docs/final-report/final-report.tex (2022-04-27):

% !TEX program = xelatex
\documentclass[czech,12pt,a4paper]{article}
\usepackage[left=35mm,right=20mm,top=25mm,bottom=25mm]{geometry}
\usepackage[autostyle]{csquotes}
\usepackage[czech]{babel}
\usepackage{titling}
\usepackage{graphicx}
\usepackage{caption}
\usepackage[list=true]{subcaption}
\usepackage{acronym}
\usepackage{setspace}
\usepackage{indentfirst}
\usepackage{listings}
\usepackage{tabularx}
\usepackage{changepage}
\usepackage[hidelinks]{hyperref}
\usepackage{xcolor}
\usepackage{sectsty}
\usepackage{tgtermes}
\usepackage{afterpage}
\usepackage{fontspec}

\setmainfont{Calibri}

\newcommand\blankpage{
    \null
    \thispagestyle{empty}
    \addtocounter{page}{-1}
    \newpage}

\definecolor{blue}{RGB}{32, 91, 157}

\graphicspath{ {./final-report/img} }
\setlength{\parindent}{2em}
\setlength{\parskip}{0.1em}
\linespread{1.5}
\sectionfont{\color{blue}\fontsize{16}{20}\selectfont}
\subsectionfont{\color{blue}\fontsize{14}{20}\selectfont}
\subsubsectionfont{\color{blue}\fontsize{12}{20}\selectfont}

\title{PlantHub}
\author{Filip Sikora, Jakub Vantuch}
\date{}

\begin{document}
\renewcommand*\listfigurename{}
\renewcommand{\figurename}{Obr.}
\renewcommand\refname{}

\afterpage{\blankpage}
\begin{titlepage}
	\vspace*{-1.75cm}
	\noindent
	\begin{center}
		\vspace*{4.5cm}
		{\fontsize{19}{20}\selectfont\textcolor{blue}{MATURITNÍ ZKOUŠKA}}
		\vspace*{7mm} \\
		\textbf{\emph{PRAKTICKÁ ZKOUŠKA Z ODBORNÝCH PŘEDMĚTŮ}}
		\vspace*{5.9cm} \\
		{\fontsize{16}{20}\selectfont\textbf{\textcolor{blue}{Zavlažovací systém PlantHub}}} \\
		\vspace*{6mm}
		{\fontsize{16}{20}\selectfont\textbf{\textcolor{blue}{Téma č. 4}}} \\
		\normalsize
	\end{center}
	\vspace*{\fill}
	\renewcommand{\arraystretch}{0.5}
	\begin{tabularx}{\textwidth}{lX@{\hskip 0.75cm}ll}
		Obor vzdělání: & \multicolumn{2}{l}{\textbf{18 – 20 – M/01 Informační technologie}} \\[10pt]
		& \multicolumn{2}{l}{\textbf{Informační technologie}} \\[10pt]
		Třída: & \textbf{4. IT} & Autor práce: & \textbf{Jakub Vantuch, Filip Sikora} \\[10pt]
		Školní rok: & \textbf{2021/22} & Vedoucí učitel práce: & \textbf{Ing. Jiří Sumbal} \\[10pt]
		& & Oponent práce: & \textbf{Ing. Beňová Jiřina} \\[10pt]
		\vspace*{1cm}
	\end{tabularx}
\end{titlepage}

\clearpage

\section*{Prohlášení autora}

\vspace*{\fill}

„Prohlašujeme, že jsme tuto práci vypracovali samostatně a použili jsme literárních pramenů a informací, které citujeme a uvádíme v seznamu použité literatury a dalších zdrojů informací.“ \\
\vspace*{0.5cm} \\
\begin{tabularx}{\textwidth}{l@{\hskip 0.75cm}X@{\hskip 1.5cm}X@{\hskip 0.75cm}l}
	Ve Frýdku-Místku, dne: & \dotfill & \dotfill & podpis \\
	& & & \\
	Ve Frýdku-Místku, dne: & \dotfill & \dotfill & podpis \\
\end{tabularx}

\clearpage

\section*{Zadání práce}

\subsection*{Jakub Vantuch}

\begin{itemize}
	\item Hardwarové řešení - stanovení cílů, volba hardware (řídící jednotka, senzory, akční členy)  
	\item Návrh obvodu a plošného spoje
	\item Fyzická realizace
	\item Naprogramování řídící jednotky
	\item Interaktivní ovládání PlantHubu z webového UI
	\item Odladění, ověření funkčnosti
\end{itemize}

\subsection*{Filip Sikora}

\begin{itemize}
	\item Softwarové řešení - stanovení cílů, volba sw platformy a konkrétního software  
	\item Konfigurace RPi jako webového serveru
	\item Vytvoření databáze
	\item Vytvoření front end
	\item Vytvoření back end
	\item Nastavení bezpečnosti
	\item Interaktivní ovládání PlantHubu z webového UI
	\item Odladění, ověření funkčnosti
\end{itemize}

\clearpage

\section*{Anotace}

PlantHub je zavlažovací systém, s plánovaným a automatickým způsobem zavlažování. Nastavení celého systému je možno upravit přes \ac{WUI}, které navíc nabízí i dashboard a prostředí pro manuální ovládání čerpadla. Jádrem našeho systému je mikropočítač \ac{RPi}, který slouží jako hostovací zařízení pro webový server, databázi, a zároveň jako řídící jednotka celého našeho systému. Systém PlantHub dále získává informace o vlhkosti půdy, teplotě, vlhkosti vzduchu, hladině vody a vykresluje je ve svém \underline{\ac{WUI}}. Ve stejné chvíli naměřená data ukládá do databáze v periodě 4 hodin. Jelikož voda časem v nádrži dojde, systém PlantHub snímá stav hladiny vody v nádrži a včas upozorní, že je třeba ji doplnit.

\section*{Klíčová slova}

\noindent zavlažování; automatizace; statistika; mikropočítač; uživatelské rozhraní

\clearpage

\tableofcontents

\clearpage

\section{Úvod} \label{secUvod}

Naším cílem je návrh, sestavení a naprogramování automatického zavlažovacího systému s názvem PlantHub. Systém se skládá z řídící jednotky (stanice), senzorů, čerpadla, nádrže a \space \underline{\ac{WUI}}. Tato stanice pravidelně snímá data ze senzorů měřících teplotu a vlhkost vzduchu, vlhkost půdy a stav hladiny v nádrži, ze které stanice přečerpává vodu. Naměřená data se živě odesílají a zobrazují ve \underline{\ac{WUI}}, ve stejné chvíli se samostatně, v periodě čtyř hodin ukládají do databáze. Přístup k naměřeným datům a \underline{\ac{WUI}} má pouze uživatel lokální sítě, do které je PlantHub připojen.

\underline{\ac{WUI}} je hostované na naší stanici. Uživatel má možnost zobrazení statistik jak živě naměřených dat, tak dat historických. \underline{\ac{WUI}} také nabízí manuální kontrolu nad čerpadlem, nastavením \underline{\ac{WUI}} a samotné řídící jednotky.

Jednotlivé součásti a moduly stanice jsme vybrali podle finanční dostupnosti a adekvátních technických požadavků na přesnost měření. Obvod jsme v testovací verzi postavili na nepájivém poli a ve finální verzi navrhli a objednali vlastní \ac{PCB}. Pro ochranu naší stanice jsme navrhli kryt, který jsme následně vytiskli na 3D tiskárně.

Hlavní program jsme napsali v programovacím jazyce Go, jehož hlavní využití je vytváření backendů webových aplikací. Tento jazyk se nám zalíbil natolik, že jsme se v něm rozhodli vytvořit jak \ac{API}, databázové funkce, tak i hlavní program. Program je rozdělen na několik sekvencí, z toho hlavní jsou měřící sekvence a sekvence controlleru, která pomocí snímání dat z databáze určuje, zda se jedná o první spuštění PlantHubu. Na základě toho určí, jestli se spustí incializační sekvence nebo sekvence samotného zavlažování.

\begin{itemize}
	\item Kapitoly \underline{\ref{secUvod}}, \underline{\ref{secAcronyms}}, \underline{\ref{secZaver}}, \underline{\ref{secObrazky}}, \underline{\ref{secReference}}, \underline{\ref{secSoftware}}, \underline{\ref{secSeznamPriloh}} jsme zpracovali společně. 
	\item Kapitoly \underline{\ref{secHardware}}, \underline{\ref{secPCB}}, \underline{\ref{secRealizace}}, \underline{\ref{secProgram}} zpracoval Jakub Vantuch.
	\item Kapitoly \underline{\ref{secWUI}}, \underline{\ref{secDB}}, \underline{\ref{secWebServer}}, \underline{\ref{secDocker}}, \underline{\ref{secBezpecnost}} zpracoval Filip Sikora.
\end{itemize}

\clearpage

\section{Seznam zkratek a pojmů} \label{secAcronyms}
\begin{acronym}
	\acro{WUI}{webové uživatelské rozhraní} \\
		Vysvětleno v kapitole \underline{\ref{secWUI}}.
	\acro{API}{application programming interface} \\
		Spojení pro přenos dat mezi zařízeními nebo programy, v našem případě, pomocí http protokolu.
	\acro{REST}{representaion programming interface} \\
		Definuje strukturu \underline{\ac{API}} tak, že zobrazuje všechna data a vytváří k nim jednoduchý přístup. Protože, ale nenačítá pouze vybraná data, není tento proces vždy vhodný, jelikož může v mnoha případech zpomalovat celou aplikaci. 
	\acro{GraphQL}{graph query language} \\
		Vysvětleno v kapitole \underline{\ref{secGraphQL}}.
	\acro{PCB}{plošný spoj} \\ 
		Předem připravené pájecí pole, vytvořené tak aby přesně odpovídalo danému obvodu.
	\acro{RPi}{Raspberry Pi} \\ 
		Mikropočítač s podporou IoT. Více v kapitole \underline{\ref{secRPi}}.
	\acro{ADC}{analogově digitální převodník} \\ 
		Vysvětleno v kapitole \underline{\ref{secADC}}.
	\acro{DHT11}{digital humidity temperature v.11} \\ 
		Senzor pro čtení hodnot teploty a vlhkosti vzduchu.
	\acro{HC-SR04}{Ultrasonický senzor vzdálenosti} \\ 
		Vysvětleno v kapitole \underline{\ref{secSonic}}.
	\acro{LED}{light emitting diode} \\ 
		Polovodičová součástka vyzařující světlo.
	\acro{DHCP}{dynamic host configuration protocol} \\ 
		Protokol pro automatické přiřazování IP adres v dané síti.
	\acro{SAR}{successive-approximation} \\ 
		Metoda převodu analogového vstupu na digitální. Více v kapitole \underline{\ref{secADC}}.
	\acro{MSB}{most significant bit} \\ 
		Vysvětleno v kapitole \underline{\ref{secADC}}.
	\acro{LSB}{least significant bit} \\ 
		Vysvětleno v kapitole \underline{\ref{secADC}}.
	\acro{Vref}[$ V_{ref}$]{Referenční napětí} \\ 
		Vysvětleno v kapitole \underline{\ref{secADC}}.
	\acro{Vin}[$ V_{in}$]{Vstupní napětí} \\ 
		Vysvětleno v kapitole \underline{\ref{secADC}}.
	\acro{Vdac}[$ V_{dac}$]{Napětí převedené z digitální do analogové hodnoty} \\ 
		Vysvětleno v kapitole \underline{\ref{secADC}}.
	\acro{IoT}{Internet of things} \\ 
		Vysvětleno v kapitole \underline{\ref{secBezpecnost}}.
\end{acronym}

\clearpage

\section{Hardware} \label{secHardware}

\subsection{Senzory}

\subsubsection{Senzor teploty a vlhkosti vzduchu DHT11}

Senzor \ac{DHT11} se skládá z jednotky pro měření teploty, jednotky pro měření vlhkosti vzduchu a převodníku. Teplotu měří senzor termistorem. Termistor je keramický polovodič, který zmenšuje svou rezistivitu, když se okolní teplota zvýší. Vlhkost měří senzor na základě rezistivity substrátu, umístěného mezi dvěma elektrodami. Tento substrát zachytává vlhkost a vytváří tak vodivé prostředí.

\subsubsection{Senzor vlhkosti půdy}

Jedná se o kapacitní senzor, který se skládá ze dvou vodivých desek a převodníku. Čidlo funguje na způsob kapacitoru, avšak jeho kapacita je ovlivněna vlhkostí, která ovlivňuje dielektrikum mezi dvěma deskami.

\subsubsection{Analogově digitální převodník MCP3008} \label{secADC}

\underline{\ac{RPi}} má v rámci general-purpose input/output (GPIO) pinů pouze digitální vstupy, protože je ale senzor vlhkosti půdy analogový, museli jsme použít \ac{ADC}.

Pomocí \underline{\ac{ADC}} v integrovaném obvodu s 10-bitovým rozlišením tedy přemapujeme analogový signál do deseti různých digitálních hodnot, kterým se také říká bitové rozlišení. \underline{\ac{ADC}} měří hodnoty od 0 až po 1023 a následně je pomocí Serial Peripheral Interface (SPI) komunikace posílá do \underline{\ac{RPi}}. \underline{\ac{RPi}} metodou \ac{SAR} definuje adresu v binární formě, srozumitelné pro digitální vstup. V první iteraci převodu se na \underline{\ac{SAR}} registru nastaví první bit na logickou hodnotu 1, stane se z něj \ac{MSB}, ten určuje pozici výstupu srovnávání dané iterace. Je nutné mít správné referenční napětí, to totiž určuje\linebreak nejvyšší možnou binární adresu. Adresa v první iteraci teda bude polovinou nejvyšší možné binární adresy + 1. V další iteraci je první bit \ac{LSB}, to je ten bit, který se v dané iteraci používá pro výstup srovnávání a druhý bit se stává \underline{\ac{MSB}}. Srovnává se hodnota zpětné konverze binární adresy s hodnotou analogového vstupu, pokud je větší, na \underline{\ac{MSB}} se nastaví logická hodnota 1, pokud menší tak logická hodnota 0. Podle počtu bitů \underline{\ac{ADC}} se určují iterace a přesnost převedené hodnoty.

\vspace*{1cm}
\noindent Příklad funkcionality, pro jednoduchost se 4-bitovým \underline{\ac{ADC}}. \\

\noindent\ac{Vref}$ = 16V$ \\
\noindent\ac{Vin}$ = 11V$ \\

1. iterace

\ac{Vdac}$ = \frac{1}{2} \underline{\ac{Vref}}$

\begin{center}
	\begin{tabular}{ |c|c|c|c| } 
		\hline
		(\underline{\ac{MSB}}) & & & \\ 
		\hline
		1 & 0 & 0 & 0 \\ 
		\hline
	\end{tabular}
\end{center}

2. iterace

	$\ac{Vdac} = 8$

	$\underline{\ac{Vin}} > \underline{\ac{Vdac}} => \underline{\ac{LSB}} = 1; \underline{\ac{MSB}} = 1$

\begin{center}
	\begin{tabular}{ |c|c|c|c| } 
		\hline
		(\underline{\ac{LSB}}) & (\underline{\ac{MSB}}) & & \\ 
		\hline
		1 & 1 & 0 & 0 \\ 
		\hline
	\end{tabular}
\end{center}

3. iterace

	$\ac{Vdac} = 12$

	$\underline{\ac{Vin}} < \underline{\ac{Vdac}} => \underline{\ac{LSB}} = 0; \underline{\ac{MSB}} = 1$

\begin{center}
	\begin{tabular}{ |c|c|c|c| } 
		\hline
		& (\underline{\ac{LSB}}) & (\underline{\ac{MSB}}) & \\ 
		\hline
		1 & 0 & 1 & 0 \\ 
		\hline
	\end{tabular}
\end{center}

4. iterace

$\ac{Vdac} = 10$

	$\underline{\ac{Vin}} > \underline{\ac{Vdac}} => \underline{\ac{LSB}} = 1; \underline{\ac{MSB}} = 1$

\begin{center}
	\begin{tabular}{ |c|c|c|c| } 
		\hline
		& & (\underline{\ac{LSB}}) & (\underline{\ac{MSB}}) \\ 
		\hline
		1 & 0 & 1 & 1 \\ 
		\hline
	\end{tabular}
\end{center}

\subsubsection{Ultrasonický senzor HC-SR04} \label{secSonic}

\ac{HC-SR04} vydává zvukové vibrace na vysoké frekvenci, neslyšitelné pro lidské ucho. Poté čeká, až se zvuk odrazí zpět od překážky a vypočítá vzdálenost, na základě času měřeného od vysílání zvukové vlny k zpětnému přijmutí. Z důvodu špatného a né tolik přesného převodu hodnot, při použití kombinace \underline{\ac{RPi}} a Go, jsme byli nuceni k tomuto senzoru připojit Arduino Nano, jako prostředníka pro správný převod hodnot. To jsme poté pomocí USB portu připojili k \underline{\ac{RPi}}.

\subsubsection{Čerpadlo}

Námi původně zvolené ponorné mini čerpadlo se skládá z DC motoru, na němž je upevněna centrifuga pro čerpání vody a vlastního pouzdra, z kterého vede otvor pro napojení odtokové hadičky. Čerpadlo je připojeno na zdroj napětí a jeho kostra je uzemněna. Bohužel v procesu testování se nám pokazilo čerpadlo, takže jsme museli vymyslet alternativní cestu, která se nakonec ukázala tou lepší variantou. Koupili jsme nové silnější čerpadlo, fungující na stejném principu, připojili k němu samostatný zdroj a přidali relé na jeho spouštění, jak je ukázáno v schématu (Obr. \ref{fig:schema-obvodu-cerpadla}), které jsme vytvořili v nástroji EasyEDA \cite{easyeda}. Zdroj \underline{\ac{RPi}} jsme použili jako signální pin pro spínání relé a vše jsme poskládali do samostatného krytu.

\vspace*{1cm}
\begin{figure}[h]
	\centering
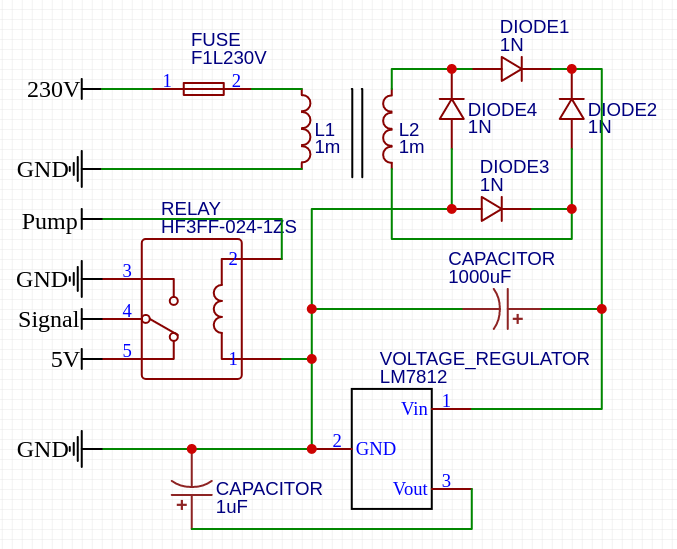
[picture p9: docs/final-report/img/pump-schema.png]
	
	\caption{Schéma obvodu čerpadla}
	\label{fig:schema-obvodu-cerpadla}
\end{figure}

\subsubsection{Tranzistor 2N2222}

Protože samotný signální pin neposkytuje dostatečné napětí pro chod čerpadla, ovládáme jej tranzistorem 2N2222. Při výměně čerpadla za jiné, které je spouštěno samostatným relé, jde napětí stále přes tranzistor. Tento tranzistor je bipolární Negative-Positive-Negative tranzistor, to znamená, že jeho polarita je nastavená tak, aby na kolektoru přijímal pozitivní napětí. Díky našemu vyměnitelnému připojení modulů, je možné čerpadlo vyměnit za jiné a přívodný kabel používat jako spouštěč čerpadla jakéhokoliv výkonu a nároků na zdroj. Při používání čerpadla na 5V stačí dva vstupní kontakty + a -, při použití čerpadla se samostatným relé stačí pouze vyměnit kabel za ten se třemi vstupy +, -, a Signal, v tomto případě bude Signal na stejném pinu jako +, pouze přidáme přívodné napětí.

\subsection{Raspberry Pi} \label{secRPi}

Vybrali jsme si jej, protože kombinuje malou velikost a vyšší výpočetní sílu, než Arduino. Musí totiž zvládnout řídit všechny senzory, ukládat data do databáze a zároveň hostuje i samotnou webovou aplikaci.

\subsubsection{Architektura ARM}

Advanced RISC Machines (ARM) je založen na Reduced Instruction Set Computing (RISC) a je to nejnověji používaná CPU architektura. Tyto procesory jsou designované na všechny moderní chytré telefony, zařízení s operačním systémem Android i Apple produkty.

\subsection{Router}

Připojení \underline{\ac{RPi}} do lokální sítě je provedeno pomocí ethernet kabelu do patřičného routeru s \ac{DHCP} mechanismem. Klientský počítač připojený do stejné sítě, si poté může jednoduše zobrazit \underline{\ac{WUI}} hostované na samotném \underline{\ac{RPi}}

\clearpage

\section{Návrh obvodu a plošného spoje} \label{secPCB}

\subsection{Testovací verze}

V prvním kroku jsme si vytvořili grafické znázornění celého obvodu (Obr. \ref{fig:graficke-znazorneni-obvodu}) v nástroji figma \cite{figma}. Testovací verzi našeho obvodu jsme postavili na nepájivém kontaktním poli. Po úspěšném otestování a ověření funkčnosti všech senzorů jsme přešli na profesionálnější řešení.

\noindent\begin{figure}[h]
	
	\caption{Grafické znázornění obvodu}
	\label{fig:graficke-znazorneni-obvodu}
\end{figure}

\clearpage

\subsection{Finální verze}

Ve finální verzi jsme navrhli naše vlastní schéma hlavního obvodu (Obr. \ref{fig:schema-obvodu}). Toto schéma jsme si nechali vytisknout společností JLCPCB a po doručení jsme na něj napájeli patřičné komponenty (Obr. \ref{fig:finalni-verze}).

\vspace*{2cm}
\begin{figure}[h]
	\begin{minipage}[t]{0.5\linewidth}
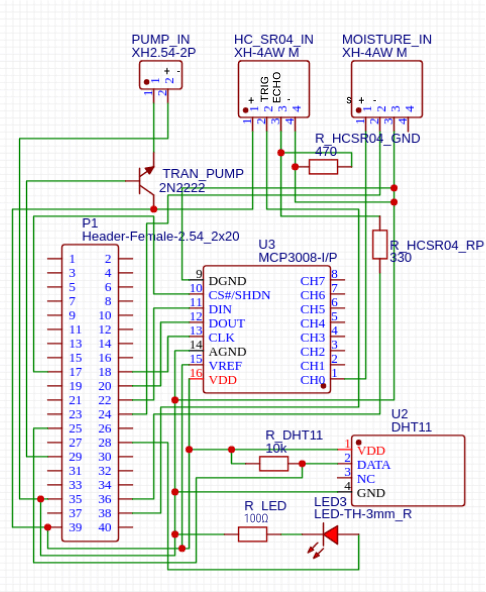
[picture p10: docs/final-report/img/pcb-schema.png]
		
		\caption{Schéma obvodu}
		\label{fig:schema-obvodu}
	\end{minipage}
	\hfill
	\begin{minipage}[t]{0.5\linewidth}
		
		\caption{Finální verze \underline{\ac{PCB}} se senzory}
		\label{fig:finalni-verze}
	\end{minipage}
\end{figure}

\clearpage

\section{Fyzická realizace} \label{secRealizace}

\subsection{Pouzdro}

Navrhli jsme vhodné pouzdro (Obr. \ref{fig:pouzdro}) pro naše \underline{\ac{RPi}}, abychom ochránili citlivé elektronické součástky a zároveň měli možnost jednoduše vyjmout stanici z krytu. Pouzdro jsme vytiskli na školní 3D tiskárně pevným Polyethylene terephthalate glycol (PETG) filamentem.

Při první verzi našeho pouzdra jsme nepřidali dostatečnou toleranci pro SD kartu, která přesahuje hranice \underline{\ac{PCB}} o několik milimetrů. Omámeni nadšením z první hmatatelné verze našeho pouzdra, jsme se neopatrně a rychle pokusili, napasovat pouzdro na \underline{\ac{RPi}}. Naší neopatrností se nám podařilo zmiňovanou SD kartu zlomit. Za odměnu jsme si tedy znova procvičili instalaci a konfiguraci operačního systému \underline{\ac{RPi}}.

\vspace*{1cm}
\begin{figure}[h]
	\centering
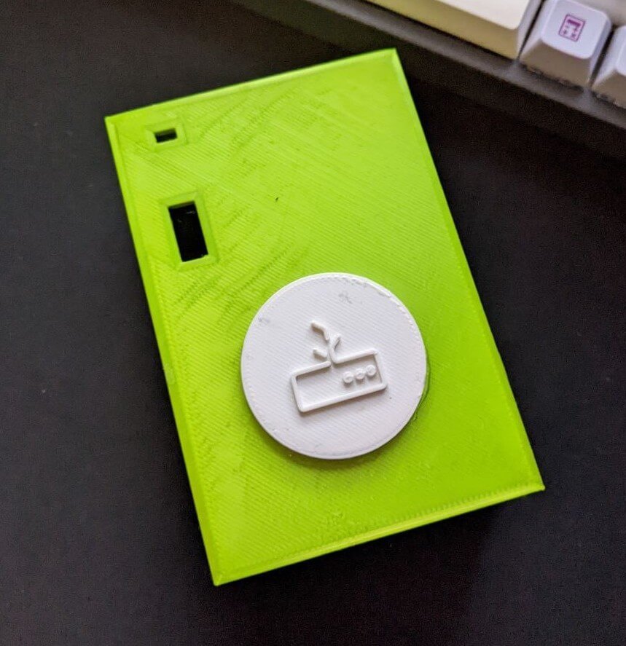
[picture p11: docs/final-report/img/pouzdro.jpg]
	
	\caption{Pouzdro}
	\label{fig:pouzdro}
\end{figure}

\subsection{Hub}

Zkompletovaný hub se tedy skládá z pouzdra, \underline{\ac{RPi}}, \underline{\ac{PCB}} a připojených senzorů, ethernet kabelu a zdrojového kabelu. Jednoduchým způsobem je možno hub rozebrat pro případnou opravu.

\vspace*{1cm}
\begin{figure}[h]
	\centering
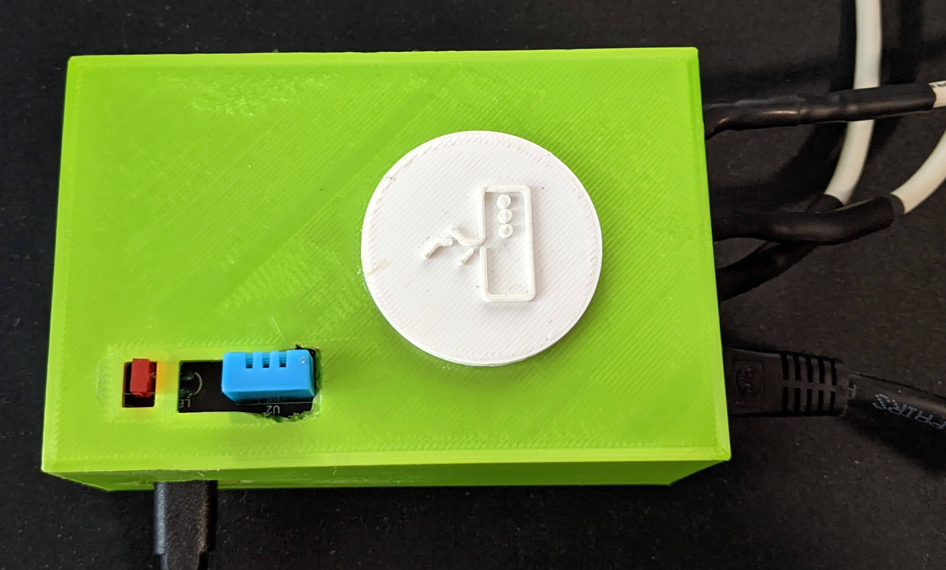
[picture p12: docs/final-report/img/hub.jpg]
	
	\caption{Hub}
\end{figure}

\clearpage

\subsection{Nádrž}

K zavlažování bylo potřeba postavit nádrž na vodu, ze které bude naše čerpadlo přečerpávat vodu k zavlažování. Nejvhodnějším řešením je nádoba s co\linebreak největším objemem, která bude jednoduše přenosná, odolná a nebude složité\linebreak připevnit na ní senzory. Naše první verze nádoby z upraveného 5L pivního soudku, nebyla tolik úspěšná. I přesto, že jsme ji natřeli antikorozní barvou, tak začala na několika místech rezivět a z důvodu špatného upevnění čerpadla i protékat. Poté co se nám pokazilo původní čerpadlo jsme se rozhodli pro změnu nádrže, kterou používáme doteď. Nádrž má stejný objem jako ta původní, tedy 5L, ale je lépe přenosná a odolnější, což přispívá k její životnosti. Přívodová hadička je do ní vedena víčkem a vystužena polyvinyl chloride (PVC) trubkou aby se nekroutila a dosáhla až na dno.

\vspace*{1cm}
\begin{figure}[h]
	\begin{minipage}[t]{0.4\linewidth}
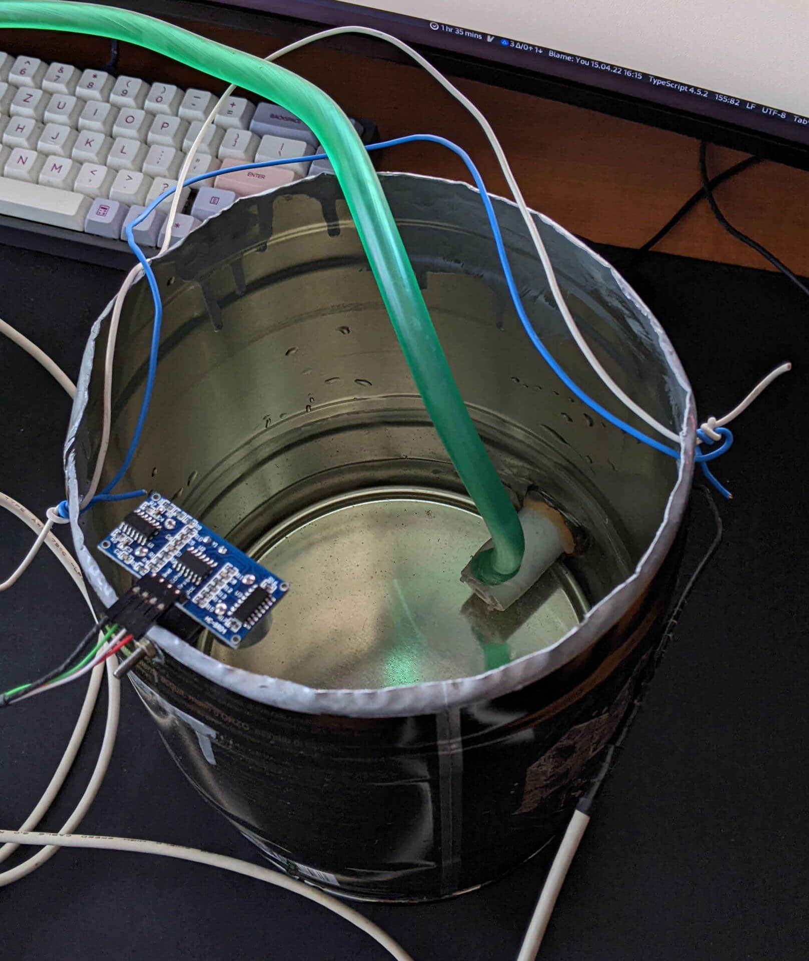
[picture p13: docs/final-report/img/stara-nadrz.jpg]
		
		\caption{První verze nádrže}
	\end{minipage}
	\hfill
	\begin{minipage}[t]{0.6\linewidth}
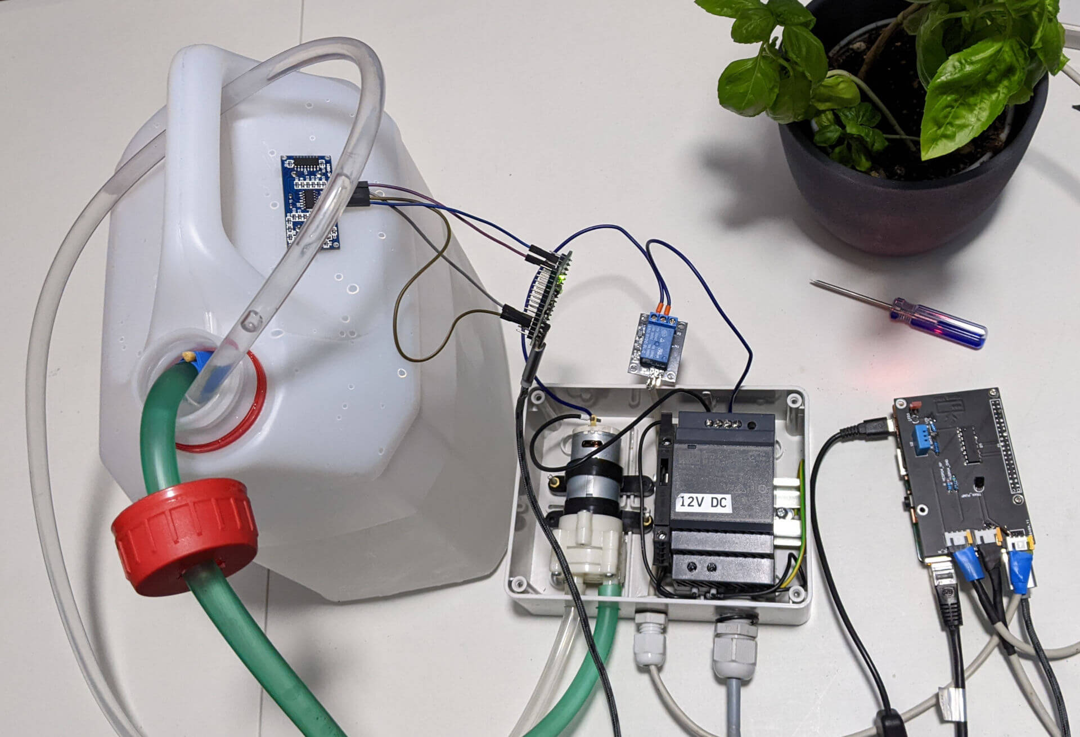
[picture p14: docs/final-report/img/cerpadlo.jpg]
		
		\caption{Finální verze nádrže}
	\end{minipage}
\end{figure}

\clearpage

\subsection{Celý systém}

Celý systém se tedy skládá z Hubu, nádrže, rostliny, routeru a klientského zařízení. Sestavení trvá asi 5 minut, protože musíme počkat, než se načte OS \underline{\ac{RPi}} a následně zapojit všechny modulární části našeho systému.

\vspace*{1cm}
\begin{figure}[h]
	\centering
	
	\caption{Celý systém}
\end{figure}

\clearpage

\section{Hlavní program} \label{secProgram}

\subsection{Postup práce}

Náš hlavní program pro zavlažování, komunikaci s databází a \underline{\ac{WUI}} jsme začali psát ve vysokoúrovňovém programovacím jazyce Python. Od toho jsme nakonec upustili, kvůli horšímu výkonu. Program jsme přepsali v programovacím jazyku Go.

\vspace*{1cm}
\begin{figure}[h]
	\centering
	
	\caption{Vývojový diagram programu}
\end{figure}

\subsection{Fáze programu}

Fáze programu se spouštějí buďto v samostatné go rutině a komunikují spolu pomocí kanálů, nebo na základě podmínek, kde se po splnění požadavků ukončí.

\subsubsection{Měření}

Senzor vlhkosti půdy a \underline{\ac{DHT11}} průběžně posílají naměřená data do \underline{\ac{WUI}}. Hlavní program ve stejné chvíli čte data ze senzorů a kontroluje jestli naměřené hodnoty nepřekračují limitní hodnoty vlhkosti půdy pro spuštění zavlažování, a ve stejné chvíli kontroluje jestli není čas spustit čerpadlo podle plánovaného zavlažování. Pokud ano, \underline{\ac{RPi}} pošle signál pro otevření tranzistoru, což spustí čerpadlo.

\subsubsection{Periodické ukládání dat}

V samostatné rutině běží funkce pro ukládání naměřených dat v periodě 4 hodin. Tato rutina, stejně jako ostatní, čte hodnoty senzorů z měřící sekvence. Naměřená data jsou následně statisticky zobrazena ve \underline{\ac{WUI}}.

\subsubsection{Controller}

Po spuštění měřící sekvence a sekvence periodického ukládání dat, se spustí buďto inicializační sekvence, nebo zavlažovací sekvence. Podle toho, jestli se v databázi nachází předchozí nastavení. Pokud předchozí nastavení nejsou nalezena, program čeká na uložení dat z \space \underline{\ac{WUI}} a \ac{LED} bliká dvakrát po sobě, dokud data nejsou dostupná. Pokud jsou data k dispozici, spustí se zavlažovací sekvence a načtou se limitní data z databáze. V periodě jedné sekundy se budou číst data o vlhkosti půdy.

\subsubsection{Inicializace}

Půda musí být ze začátku suchá. Senzor vlhkosti půdy zasuneme co nejhlouběji do půdy. \underline{\ac{RPi}} bude chvíli sbírat data a pak je zprůměruje do hodnoty, která bude sloužit jako limit pro spuštění čerpadla.

Ve \underline{\ac{WUI}} jde navíc ještě manuálně nastavit hranice vlhkosti půdy pro spuštění čerpadla.

Nastavit se dá také množství vody, které bude přečerpáno při jednom spuštění a jaká je hranice pro přijatelnou výšku hladiny vody v nádrži. Pokud nejsou tyto hodnoty uvedeny, čerpadlo bude vodu přečerpávat, dokud se nezmění hodnota kapacitního čidla pro měření vlhkosti půdy a \space \underline{\ac{HC-SR04}} použije výchozí nastavení.

\subsubsection{Zavlažování}

Čerpadlo začne čerpat vodu a zavlažovat rostlinu. Voda se čerpá tak dlouho, dokud senzor vlhkosti půdy nezmění svou hodnotu, nebo dokud není vyčerpán limit přečerpané vody na jedno spuštění.

\subsubsection{Kontrola}

Po ukončení přečerpávání se spustí \underline{\ac{HC-SR04}} a změří výšku hladiny vody. Naměřená data poté odešle do \underline{\ac{RPi}}, kde se uloží do databáze. Pokud bude naměřená hodnota nižší, než je limitní hodnota, začne blikat \underline{\ac{LED}} a \underline{\ac{RPi}} odešle upozornění o doplnění nádrže do \underline{\ac{WUI}}. Jakmile bude hladina vody doplněna, signalizace se vypne.

\subsubsection{Ukládání dat}

Náš systém ukládá zvlášť periodicky naměřená data a data naměřená před zavlažováním. Dále ukládá nastavení, jak pro limity k zavlažování, tak pro \underline{\ac{WUI}}.

\subsection{Programovací jazyk Go}

Go je open-source programovací jazyk, který byl vytvořen společností Google v roce 2009. Je to stále relativně nový programovací jazyk, který se nevyvinul z jiných jazyků jako C\# a Java. Go ignoruje teorii o programovacích jazycích. Místo toho, aby se zaměřoval na akademické teorie, zaměřuje se na reálné praktiky, používané pro vývoj next-gen v cloudových, distribuovaných a souběžných aplikacích.

Jazyk Go je staticky typovaný a využívá garbage collector (automatický správce paměti). Jedná se o kompilovaný programovací jazyk, který své binární soubory kompiluje pro každou platformu. Dá se zařadit do skupiny C jazyků, podle jeho základní syntaxe. Go poskytuje expresivní syntax s jednoduchým typovým systémem a má vestavěné nástroje pro paralelní programování. Výkon Go je srovnatelný s jazyky C a C++, ale zároveň nabízí rychlý a jednoduchý vývoj aplikací.

Stejně jako C a C++ se Go kompiluje do nativního strojového kódu, takže
nepotřebujeme běhové prostředí jako Common Language Runtime (CLR) a Java Virtual Machine (JVM). To má řadu výhod, třeba při distribuci aplikace v aplikačních kontejnerech, jako je Docker.

\subsubsection{Paralelní programování v Go}

Vývoj počítačů se v průběhu posledního desetiletí značně posunul. V minulosti aplikace běžely na počítačích pouze s jediným procesorovým jádrem. Dnes jsou standartně k vidění čtyřjádrové procesory v uživatelských počítačích, dokonce i naše \underline{\ac{RPi}} má dvě jádra. Stále používáme programovací jazyky a technologie navržené v éře, kdy byly dostupné pouze jednojádrové procesory.

Většina programovacích jazyků dnes nabízí knihovny, nebo frameworky pro \linebreak paralelní programování, ale nemají tuto vlastnost zabudovanou přímo v jádře jazyka. V Go je paralelní programování součástí jazyka, už od samotného počátku. Používá takzvané Gorutiny, které umožňují spouštět funkce souběžně. Souběžné funkce pak mezi sebou mohou komunikovat a předávat data pomocí kanálů. Dokonce i některé standardní knihovny jazyka mají zabudovanou souběžnost. Například standardní knihovna `net/http' pro programování HTTP, zpracovává přicházející požadavky souběžně pomocí Gorutin.

\subsubsection{Typový systém}

Pragmatický design Go neobsahuje klíčové slovo pro třídu a jeho objektová orientace je odlišná od tradičních, objektově orientovaných programovacích jazyků. V Go nahrazuje funkci tradiční třídy typ struct. Dědění není v go podporováno, ale podporuje kompozici typů (Příloha 1).

\clearpage

\section{WUI} \label{secWUI}

\subsection{Programování WUI}

Webovovou aplikaci jsme napsali pomocí javascriptového frameworku
React.js, CSS frameworku Tailwind a programovacího jazyku Typescript, který je dialektem javascriptu, podporující volitelné statické typování. JavaScript je dynamicky typovaný jazyk. Statické typování je výhodné hlavně u větších aplikací, kde zjednodušuje odchytávání chyb v oblasti datových typů, nebo jim předchází úplně.

Ve webovém rozhraní je možné zobrazit si statisky, jak živě naměřených dat, tak dat uložených v databázi. Z OpenWeather \underline{\ac{API}} získáváme data o předpovědi počasí a do dahsboardu zobrazujeme předpovědi na dalších 15h.

\subsection{Inicializační formulář}

\begin{figure}[h]
	\centering
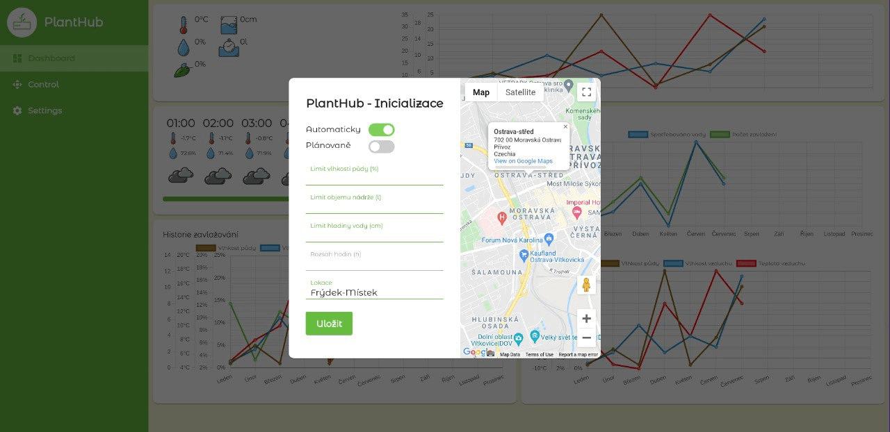
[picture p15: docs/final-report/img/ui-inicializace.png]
	
	\caption{Inicializační formulář}
\end{figure}

Okno prvotního nastavení obsahuje uživatelsky přívětivé rozhraní, které uživatele provede nastavením systému. Nastaví se mód zavlažování, limitní hodnoty a lokace, ze které má PlantHub ukazovat předpověď počasí.

\clearpage

\subsection{Dashboard}

\begin{figure}[h]
	\centering
	
	\caption{Dashboard}
\end{figure}

Prostředí dashboardu (nástěnky) je hlavní částí webové aplikace. Uživatel zde může sledovat aktuální dění v podobně real-time dat ze senzorů a aktuálního stavu nádrže. K tomu jsme mu připravili praktickou kartu s předpovědí počasí a karty s grafy historických dat.

Prvním takovýmto grafem je historie zavlažování. Tento graf zobrazuje statisticky jaká byla teplota, vlhkost vzduchu a vlhkost půdy, těsně před zavlažováním. Na pravé straně jsou umístěny další dva grafy, první zobrazuje spotřebu vody při zavlažování za jednotlivé měsíce. Druhý potom vykresluje historické průměry naměřených dat v jednotlivých měsících.

\clearpage

\subsection{Manuální ovládání}

\begin{figure}[h]
	\centering
	
	\caption{Manuální ovládání}
\end{figure}

Manuální ovládání čerpadla dovoluje uživateli kdykoliv spustit zavlažování. Po dokončení manuálního zavlažování, se také spustí kontrola hladiny vody v nádrži. Při úpravě limitních hodnot, či jiných nastavení řídící jednotky, je nutno zařízení restartovat. K tomu v menu \underline{\ac{WUI}} slouží možnost \enquote{Restart HW}.

\clearpage

\subsection{Nastavení}

\begin{figure}[h]
	\centering
	
	\caption{Nastavení}
\end{figure}

V nastavení lze změnit nastavení aplikace, včetně limitů pro zavlažování a doby zavlažování. Na výběr máme automatické a plánované zavlažování. V prvním režimu PlantHub zavlažuje automaticky, kdy a jak moc má zavlažit, vyhodnotí z dat senzoru vlhkosti půdy. Při plánovaném zavlažování nastavíme intervaly, ve kterých se má zavlažovat. V nastavení aplikace se nastavuje lokace pro předpověď počasí. Nastavení se ukládají do databáze.

\clearpage

\subsection{Notifikace}

\begin{figure}[h]
	\centering
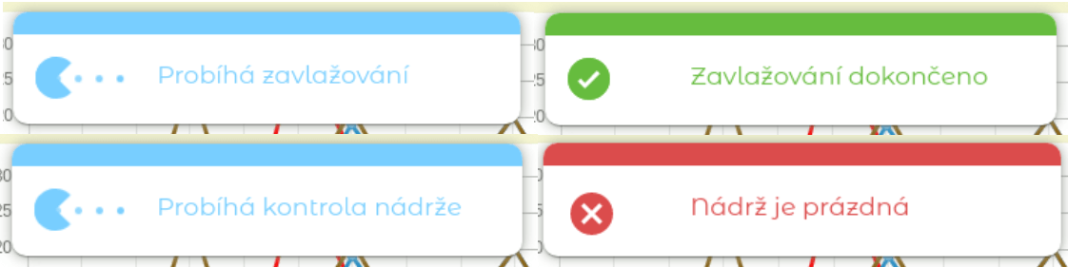
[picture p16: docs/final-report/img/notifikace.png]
	
	\caption{Sada notifikací}
\end{figure}

Součástí webového rozhraní jsou i praktické notifikace, které uživatele upozorňují na aktuální stav PlantHubu. Poskytují vizuální zpětnou vazbu, při průběhu zavlažování a kontrole nádrže. Při úspěšném dokončení zavlažování, informují uživatele. V případě, že je nádrž na vodu prázdná, tak uživatele s touto skutečností seznámí.

\clearpage

\section{Databáze} \label{secDB}

\subsection{SQL}

Pro databázi jsme se rozhodli použít relační databázový systém PostgreSQL.\@ Jak vyplývá z názvu, jedná se o Structured Query Language (SQL) databázi, ty jsou vhodné pro ukládání velkého objemu dat, jako právě data z našich senzorů. Webová aplikace používá pro přístup k datům z databáze \ac{GraphQL} \space \underline{\ac{API}}. Naše schéma, jako je ukázáno na (Obr. \ref{fig:schemaDB}), je propojeno pomocí \underline{\ac{GraphQL}}.

\vspace*{1cm}
\begin{figure}[h]
	\centering
	
	\caption{Schéma databáze}
	\label{fig:schemaDB}
\end{figure}

\subsection{GraphQL} \label{secGraphQL}

Jedná se o typ přenosu dat z možností filtrace a dotazovací funkcionality. V mnoha ohledech je to konkurent řešení přenosu dat pomocí \ac{REST} \space \underline{\ac{API}}.\@ Nabízí rychlejší tvorbu \underline{\ac{API}} \space a také umožňuje efektivnější přístup k datům z databáze. Umožňuje vybrat pouze data, která momentálně aplikace používá a dovoluje vynechat data, která zrovna potřebná nejsou.

\clearpage

\section{Webový server} \label{secWebServer}

Web server jsme napsali v moderním jazyku Go, který nyní získává na popularitě, hlavně mezi cloudovými vývojáři a v oblasti vývoje microservices. Dokáže se v rychlosti provedení programu přiblížit k nízkoúrovňovým jazykům, jako je C nebo Rust, ale zároveň zůstává velmi lidsky čitelný a jednoduchý na použití. Na rozdíl od jazyků jako C a Rust, má například garbage collector (automatický správce paměti), který periodicky čistí paměť a zabraňuje memory leakům.

\clearpage

\section{Docker a kontejnerizace} \label{secDocker}

Kontejnerizace je zabalení aplikace spolu se všemi nutnými komponenty, jako jsou knihovny, frameworky a další závislosti (dependencies), do svého vlastního \enquote{kontejneru}, který je izolovaný od zbytku systému.

Daná aplikace nebo program, potom může být spuštěna konzistentně kdekoliv, nezávisle na prostředí, operačním systému i architektury hostového systému. Aplikace běží zcela nezávisle na zbytku systému. Kontejner imituje jakousi bublinu, která aplikaci obklopuje a izoluje. Je to v podstatě plně funkční a přenosné výpočetní prostředí. Toto je hlavním důvodem, proč jsme zvolili kontejnerizaci pro náš projekt. V případě, že bychom chtěli vyrobit více jednotek, tak můžeme na jednotlivé \underline{\ac{RPi}} nasadit předpřipravené kontejnery a nemusíme se skoro vůbec zabývat konfigurací operačního systému \underline{\ac{RPi}}.

Kontejnery poskytují alternativu ke klasickému vývoji aplikací na jedné platformě, nebo operačním systému. V něktérých případěch nevýhodou kontejnerů je, že mohou zhoršit kompatibilitu aplikace s jinými systémy, které nemusí sdílet stejné prostředí, jako systém, na kterém byla aplikace původně vyvíjena. Tato zhoršená kompatibilita může způsobit různorodé problémy a chyby aplikace, které se potom musí řešit navíc. V realitě to pak znamená prodloužený čas vývoje, snížení produktivity a frustraci vývojářů.

Díky zabalení aplikace v kontejneru, pak může být jednoduše spouštěna napříč platformami a operačními systémy. Také ji můžeme jednoduše přesouvat mezi zařízeními, protože vše co potřebuje, má zabaleno ve svém kontejneru.

Myšlenka kontejnerizace existuje dlouho. Docker, ale v roce 2013 stanovil standart kontejnerizace technologií Docker Engine. Docker Engine přinesl jednoduché nástroje pro vývoj, díky nimž se stal vývoj s použitím kontejnerů snadný. Zavedl také univerzální přístup k distribuci kontejnerů, což zrychlilo adopci kontejnerizace. Dnes si vývojáři mohou vybrat z nabídky kontejnerizačních platforem, které podporují standart Open Container Initiative, vyvinuté společností Docker.

\subsection{Výhody kontejnerizace}

Kontejnery sdílejí kernel (jádro) operačního systému s jejich hostem. Kontejnery tak nepotřebují svůj vlastní operační systém a díky tomu jsou výpočetně nenáročné. Můžou tak běžet stejně na jakémkoliv zařízení, ať už se jedná o malé \underline{\ac{RPi}}, nebo cloudová datacentra.

\subsection{Kontejnery vs. virtuální počítače}

Virtuální počítač je virtuální prostředí, které funguje jako běžný počítač. Má svůj vlastní virtuální procesor, paměť, síťový adaptér a úložiště. Tyto komponenty jsou virtualizovány na fyzickém hardwaru hostujicího systému.

Kontejnerizace a virtualizace jsou podobné v tom, že poskytují plnou izolaci aplikace, aby byla jednoduše spustitelná v různých typech prostředí. Hlavním rozdílem je velikost, výpočetní náročnost a přenosnost.

Virtuální počítač je větší z této dvojice, jeho velikost je typicky měřena v gigabytech. Obsahuje svůj vlastní operační systém, který mu dovoluje provádět několik výpočetně náročných funkcí zároveň. Jeho zvýšený výpočetní výkon, mu umožňuje zapouzdřit, rozdělit, duplikovat a emulovat celé servery, operační systémy, desktopy, databáze a počítačové sítě.

Kontejnery jsou mnohem menší, velikostí většinou v řádech megabytů a neobsahují nic víc, než samotnou aplikaci a nutné prostředí pro její běh.

Virtuální počítače fungují dobře v tradičních a monolitických IT architekturách. Kontejnery byly navrženy s důrazem na nejnovější a vznikající technologie, jako cloudy, CI/CD a DevOps.

\clearpage

\section{Bezpečnost} \label{secBezpecnost}

Náš projekt spadá do kategorie zařízení \ac{IoT}, neboli Internet of Things. Česky by to byl \enquote{Internet věcí}. Bezpečnost \underline{\ac{IoT}} zařízení bylo vždy velké téma. Zařízení \underline{\ac{IoT}} jsou totiž nechvalně známé svou nedostatečnou bezpečností. Tyto zařízení často bývají pro útočníky pomyslnou bránou do lokální sítě jejich oběti.

Rozmach těchto zařízení u běžných lidí tento problém zvýraznil. Mezi poslední trendy technologie patří chytré domy, kde je vše ovládáno chytrými zařízeními, které lze nastavovat na dálku pomocí telefonu. Hlavní charakteristikou \underline{\ac{IoT}} je schopnost zařízení připojit se k internetu a interagovat se svým okolím pomocí sběru a výměny dat. Jedná se o zařízení od chytrých ledniček, termostatů, automatických vysavačů a žaluzií, až po žárovky. Tím, že jsou všechny tyto zařízení připojeny k internetu, jen zvyšujeme šanci napadení.

Náš projekt je zcela nezávislý na serverech v cloudu, místo toho je komunikace s PlantHubem zprostředkována pouze v lokální síti. Tímto designem jsme sice znemožnili přístup k PlantHubu mimo lokální síť, ale zároveň jsme velmi pozitivně ovlivnili bezpečnost celého systému. Zařízení stále musí být připojeno k internetu, z důvodu získávání dat ohledně předpovědi počasí a polohy z \underline{\ac{API}} třetí strany. K přístupu a možnosti ovládání mimo lokální síť, bychom potřebovali VPN server v lokální síti.

K tomu jsme vybrali Fedora \underline{\ac{IoT}}, jako naši linuxovou distribuci. Tato distribuce je přímo určená zařízením jako je naše, jak již vyplývá z názvu distribuce. Byla navržena s velkým důrazem na bezpečnost a základní nastavení distribuce je velmi bezpečné. Mezi bezpečnostní funkce patří SecureBoot, automatické šifrování úložiště, firewall a další.

\clearpage

\section{Závěr} \label{secZaver}

Náš projekt je stále ve vývoji a některé z funkcí tohoto projektu, nefungují podle našich představ. I přes to, je náš systém v této chvíli použitelný. Myslíme si, že tento projekt má v budoucnu potenciál stát se úspěšným startupem. Proto plánujeme pokračovat v jeho vývoji i po maturitě.

Abychom však tento projekt mohli pojmout jako plně funkční systém, museli bychom ještě dokončit a předělat některé klíčové části. Jednalo by se především o rozdělení hostingu webové aplikace a databáze na samostatný server. Zajištění modulárnosti celého systému rozdělením řídící jednotky na samostatné moduly a hub zodpovědný za jejich provoz. V dalších neprioritních krocích, se můžeme bavit o dokončení plánované tmavé verze \underline{\ac{WUI}} a přidání podpory více jazyků. Pro odlišení od konkurence mnoha jiných zavlažovacích systémů, přidáme chytré funkce vypočítávání spotřeby vody, energie a na základě předpovědi počasí, typu rostliny a lokace. Uvažovali jsme také nad soukromou databází rostlin a jejich rozdělení, na základě způsobu pěstování. V komerčním modelu, bychom mohli z této databáze vytvořit placené \underline{\ac{API}}, pro jiné zavlažovací systémy.

Tato práce, byla pro nás velkým přínosem. Naučili jsme se mnoho nových dovedností a načerpali nové informace, které v naší profesi bezpochyby dále využijeme.

\clearpage

\section{Seznam obrázků} \label{secObrazky}

\vspace*{-1.5cm}
\listoffigures

\clearpage

\section{Reference} \label{secReference}

\begin{thebibliography}{9}
	\vspace*{-1.5cm}
	\bibitem{texbook}
	“Home,” LaTeX, 06-May-2021. [Online]. Dostupné z: \underline{\href{https://latex-tutorial.com/}{https://latex-tutorial.com/}}. [Zpřístupněno: 10-Dubna-2022]. 

	\bibitem{golang}
	“Build fast, reliable, and efficient software at scale,” Go. [Online]. Dostupné z: \underline{\href{https://go.dev/}{https://go.dev/}}. [Zpřístupněno: 10-Dubna-2022]. 

	\bibitem{react}
	“React – a JavaScript library for building user interfaces,” – A JavaScript library for building user interfaces. [Online]. Dostupné z: \underline{\href{https://reactjs.org/}{https://reactjs.org/}}. [Zpřístupněno: 10-Dubna-2022]. 

	\bibitem{tailwindcss}
	“Rapidly build modern websites without ever leaving your HTML.,” Tailwind CSS. [Online]. Dostupné z: \underline{\href{http://www.tailwindcss.com/}{http://www.tailwindcss.com/}}. [Zpřístupněno: 10-Dubna-2022]. 

	\bibitem{typescript}
	“JavaScript with syntax for types.,” TypeScript. [Online]. Dostupné z: \underline{\href{http://www.typescriptlang.org/}{http://www.typescriptlang.org/}}. [Zpřístupněno: 10-Dubna-2022]. 

	\bibitem{vscode}
	Microsoft, “Visual studio code - code editing. redefined,” RSS, 03-Nov-2021. [Online]. Dostupné z: \underline{\href{https://code.visualstudio.com/}{https://code.visualstudio.com/}}. [Zpřístupněno: 10-Dubna-2022]. 

	\bibitem{goland}
	“Goland by jetbrains: More than just A go ide,” JetBrains. [Online]. Dostupné z: \underline{\href{https://www.jetbrains.com/go/}{https://www.jetbrains.com/go/}}. [Zpřístupněno: 10-Dubna-2022]. 

	\bibitem{git}
	Git. [Online]. Dostupné z: \underline{\href{https://git-scm.com/}{https://git-scm.com/}}. [Zpřístupněno: 10-Dubna-2022]. 

	\bibitem{figma}
	“The Collaborative Interface Design Tool.,” Figma. [Online]. Dostupné z: \underline{\href{https://www.figma.com/}{https://www.figma.com/}}. [Zpřístupněno: 10-Dubna-2022]. 

	\bibitem{freecad}
	“Freecad,” FreeCAD. [Online]. Dostupné z: \underline{\href{https://www.freecadweb.org/}{https://www.freecadweb.org/}}. [Zpřístupněno: 10-Dubna-2022]. 

	\bibitem{easyeda}
	An easier and PowerfulOnline PCB design tool. EasyEDA. [Online]. Dostupné z: \underline{\href{https://easyeda.com/}{https://easyeda.com/}}. [Zpřístupněno: 10-Dubna-2022]. 
\end{thebibliography}

\clearpage

\section{Seznam použitého softwaru} \label{secSoftware}

\begin{enumerate}
	\item Visual Studio Code
	\item GoLand
	\item EasyEDA
	\item FreeCAD
	\item Figma
	\item Git
\end{enumerate}

\clearpage

\section{Seznam příloh} \label{secSeznamPriloh}

\begin{itemize}
	\item Příloha 1: Typový systém v Go.png
	\item Příloha 2: Source-code
	\item Příloha 3: Pcb
	\item Příloha 4: Case
\end{itemize}

\end{document}

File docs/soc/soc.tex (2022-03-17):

\documentclass[12pt,a4paper]{article}
\usepackage[utf8]{inputenc}
\usepackage[sfdefault]{ClearSans}
\usepackage[T1]{fontenc}
\usepackage[left=25mm,right=25mm,top=25mm,bottom=25mm]{geometry}
\usepackage[czech]{babel}
\usepackage{titling}
\usepackage{graphicx}
\usepackage{caption}
\usepackage[list=true]{subcaption}
\usepackage{acronym}
\usepackage{setspace}
\usepackage{indentfirst}
\usepackage{hyperref}
\usepackage{listings}

\newcommand{\subtitle}[1]{%
	\posttitle{%
		\par\end{center}
		\begin{center}\large#1\end{center}
		\vskip0.5em}%
}

\newcommand*\wildcard[2][5cm]{\vspace*{2cm}\parbox{#1}{\centering\hrulefill\par#2\par}}

\graphicspath{ {./img/} }

\onehalfspacing
\setlength{\parindent}{2em}
\setlength{\parskip}{0.1em}

\title{PlantHub}
\subtitle{soutěž KYBER STOČ 2022 }
\author{Filip Sikora, Jakub Vantuch}
\date{}

\begin{document}

\begin{titlepage}
	\begin{center}
		\LARGE{STŘEDOŠKOLSKÁ ODBORNÁ ČINNOST}
		\vspace{0.5cm} \\
		\Large{Obor č. 10\\ Elektrotechnika elektronika a telekomunikace}
		\vspace{7cm} \\
		\Huge\textbf{Zavlažovací systém PlantHub}
		\vfill
		\normalsize
		\begin{minipage}{0.7\linewidth}
			Filip Sikora \\
			Jakub Vantuch \\
			Moravskoslezský kraj
		\end{minipage}%
		\begin{minipage}{0.25\linewidth}
			Frýdek-Místek 2022
		\end{minipage}
	\end{center}

\end{titlepage}

\section*{Prohlášení}

Prohlašuji, že jsem svou práci SOČ vypracoval/a samostatně a použil/a jsem
pouze prameny a literaturu uvedené v seznamu bibliografických záznamů.

Prohlašuji, že tištěná verze a elektronická verze soutěžní práce SOČ jsou
shodné.

Nemám závažný důvod proti zpřístupňování této práce v souladu se zákonem č.
121/2000 Sb., o právu autorském, o právech souvisejících s právem autorským a o
změně některých zákonů (autorský zákon) ve znění pozdějších předpisů.

Ve Frýdku-Místku dne 4. 3. 2022

\begingroup
  \centering
  \wildcard{Filip Sikora}
  \hspace{1cm}
  \wildcard{Jakub Vantuch}
  \par
\endgroup

\clearpage

\section*{Anotace}

PlantHub je automatický zavlažovací systém s WUI.
Jádrem našeho systému je mikropočítač RPi s procesorovou architekturou ARM,
GPIO a možností připojení pomocí ethernetu.
Vybrali jsme si jej, protože kombinuje malou velikost a vyšší výpočetní sílu
než Arduino. Musí totiž zvládnout řídit všechny senzory, ukládat data do
databáze a zároveň hostuje i samotnou webovou aplikaci. Systém PlantHub dále
získává informace o teplotě, vlhkosti a tlaku vzduchu a promítá je ve svém
WUI. Ve stejné chvíli naměřená data ukládá do databáze v periodě 4
hodin. Jelikož voda časem z nádrže dojde systém PlantHub snímá stav hladiny
vody v nádrži a včas upozorní, že je třeba doplnit vodu.

\section*{Klíčová slova}

zavlažování; automatizace; statistika; živě; RaspberryPi; uživatelské rozhraní

\clearpage

\tableofcontents

\clearpage

\section{Úvod}

Naším cílem je návrh, sestavení a naprogramování automatického zavlažovacího
systému s WUI a ukládáním naměřených dat do databáze
pro pozdější statistiky. Tato stanice pravidelně snímá data ze senzorů měřících
teplotu a vlhkost vzduchu, vlhkost půdy a stav hladiny v nádrži, z té pak
stanice přečerpává vodu pomocí čerpadla spouš-těného tranzistorem. Naměřená data
se posílají živě pomocí REST API prostřednictvím
protokolu HTTP do WUI a ve stejné
chvíli se v periodě čtyř hodin ukládají do PostgreSQL databáze běžící v docker
containeru pro pozdější
statistiky
změn teploty, vlhkosti vzduchu, vlhkosti půdy a počtů zavlažování v časovém
rozsahu zobrazitelné v dashboardu WUI. Pro načtení historických dat z databáze
používáme GraphQL API, jelikož nabízí šetrnější přístup k datům, vybráním pouze
těch záznamů z tabulky, které opravdu využíváme. V případě nedostupnosti
serveru by se ve WUI měla pořád načítat živě naměřená data z REST API. Přístup
k naměřeným datům a
WUI má pouze
uživatel lokální
sítě, do které je planthub připojen pomocí ethernet kabelu, z čehož vyplývá, že
pro správnou funkci
stanice je zapotřebí router s přístupem k internetu a DHCP serverem.

Ve WUI hostovaném na naší stanici, a sestavém pomocí javascriptového frameworku
React.js, CSS frameworku
Tailwind a programovacího jazyku Typescript, který je supersetem javascriptu,
podporujícím volitelné statické typování, má uživatel
možnost zobrazení statistik jak živě naměřených dat tak dat historických v
nastavitelných grafech dashboardu. WUI také nabízí manuální kontrolu nad
čerpadlem s časovačem začátku zavlažování a restartem hlavního programu.
Nastavitelné je jak WUI tak i samotné faktory zavlažování jako je limit
vlhkosti
půdy, doba zavlažování nebo limit hladiny vody.

Jednotlivé součásti a moduly stanice jsme vybrali podle finanční dostupnosti a
adekvátních technických
požadavků na přesnost měření.
Zapojení těchto modulů do obvodu jsme prvně provedli ve webové aplikaci
EasyEDA, která nabízí jednoduché prostředky pro návrh technických
schémat. Tento obvod jsme poté v testovací verzi postavili na nepájivém
poli a ve finální verzi navrhli a objednali vlastní PCB. Pro ochranu naší
stanice jsme v open-source programu FreeCad navrhli model krytu, který jsme
následně vytiskli na 3D tiskárně. Vymstila se nám však nepřesnost rozměrů krytu
a při vkládání stanice do krytu se nám podařilo zlomit SD kartu s operačním
systémem, daty a nasazenými programy. Po reinstalaci operačního systému jsme
opravili rozměry vytvořeného modelu krytu a
vytiskli kryt podruhé, tentokrát ve správných rozměrech.

Hlavní program jsme v prvotní verzi psali ve vysokoúrovňovém programovacím
jazyce Python, od kterého jsme nakonec upustili kvůli vysokým technickým
nárokům. Naše rozhodnutí nás nakonec dovedlo k jazyku
Go vytvořeného Googlem a určeného pro concurrency, rychlou kompilaci i průběh
programu, backend webových aplikací a mnoho
další funkcionality. Tento jazyk se nám zalíbil natolik že jsme se v něm
rozhodli
udělat jak API,
databázové funkce tak i hlavní program. Program je rozdělen na několik sekvencí
z toho hlavní jsou měřící sekvence kde se každou sekundu provádí měření dat ze
senzorů a následné odesílání na REST API webové aplikace a channely vytvořené
pro komunikaci mezi go rutinama a sekvence controlleru, která pomocí snímání
dat z databáze určuje jestli se jedná o první spuštění PlantHubu, a podle toho
určí jestli se spustí incializační sekvence nebo sekvence zavlažování.

\section{Hardware}

Potřebujeme vyvinout vhodné pouzdro pro naše Raspberry, abychom ochránili
citlivé elektronické součástky a ve stejné chvíli měli možnost jednoduše
vyjmout stanici z krytu. Budeme ho tisknout na 3D tiskárně pevným PTG
filamentem. K
zavlažování je potřeba postavit i nádrž na vodu, ze které bude naše čerpadlo
přečerpávat vodu k zavlažování, proto jsme se rozhodli pro nádobu s co
nejvetším objemem a postavili ji z upraveného 5L soudku.

\subsection{Senzory}

\subsubsection{DHT11}

Senzor DHT11 se skládá z jednotky pro měření teploty, jednotky pro měření
vlhkosti a převodníku.

Teplotu měří senzor termistorem. Thermistor je keramický polovodič, který
zmenšuje svou rezistivitu, když se okolní teplota zvýší.

Vlhkost měří senzor na základě rezistivity substrátu umístěného mezi dvěma
elektrodami. Tento substrát zachytává vlhkost a vytváří tak vodivé prostředí

\subsubsection{Senzor vlhkosti půdy}

Jedná se o kapacitní senzor, ten se skládá ze dvou vodivých desek a převodníku.
Čidlo funguje na způsob kapacitoru avšak jeho kapacita je ovlivněna vlhkostí,
která ovlivňuje dielektrikum mezi dvěma deskami.

\subsubsection{MCP3008}

RPi má v rámci GPIO pouze digitální vstupy, protože je ale senzor vlhkosti půdy
analogový museli jsme použít ADC převodník. Přemapujeme tedy analogový signál
do
osmi různých digitálních hodnot, kterým se také říká 3bitové rozlišení, to
definuje tu nejmenší hodnotu změny, který převodník dokáže rozlišit, této
hodnotě se říká LSB (least significant bit). ADC poté pomocí SAR
definuje adresu v binárním podání srozumitelným pro digitální vstup.

\begin{figure}[h]
	\centering
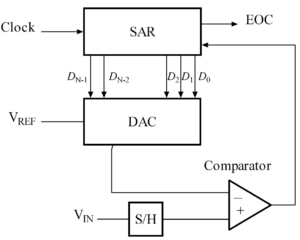
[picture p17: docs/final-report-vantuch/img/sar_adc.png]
	
	\caption{SAR}
\end{figure}

\subsubsection{HC-SR04}

HC-SR04 vydává zvukové vibrace na vysoké frekvenci, neslyšitelné pro lidské
ucho. Poté čeká, až se zvuk odrazí zpět, a vypočítá vzdálenost na základě času
měřeného od vysílání zvukové vlny k zpětnému přijmutí

Všechny naměřené údaje jsou v převodníku senzoru přepočítány na jednotky dané
veličiny a odeslány analogovým signálem do řídící jednotky.

\subsubsection{Čerpadlo}

Naše zvolené čerpadlo se skládá z DC motoru, na němž je upevněna centrifuga pro
čerpání vody a vlastního pouzdra, z kterého vede otvor pro napojení odtokové
hadičky. Čerpadlo je připojeno na zdroj napětí 5V a zem.

\subsubsection{2N2222}

Protože samotný signální pin neposkytuje dostatečné napětí pro chod čerpadla
ovládáme jej NPN tranzistorem. Díky našemu vyměnitelnému připojení modulů je
možné čerpadlo vyměnit a přívodný kabel používat jako spouštěč čerpadla
jakéhokoliv výkonu a nároků na zdroj.

\clearpage

\subsection{Architektura ARM}

ARM je nejnovější CPU architektura. Využívají ji všechny moderní chytré telefony, zařízení s operačním systémem Android i Apple produkty. Dnes už mají ARM procesory zařízení s Windows nebo MacOS.

% ARM je založen na RISC (Reduced Instruction Set Computing), tyto procesory jsou designované na 

\subsection{Obvod}

Testovací verzi našeho obvodu jsme postavili na nepájivém kontaktním poli,
které jsme používali pouze v testovací verzi. Jakmile jsme měli vše plně
odzkoušeno a plně otestováno přešli jsme na profesionálnější řešení.
Což tedy v druhé fázi znamenalo sestrojit a nechat vytisknout náš vlastní obvod
přepracovaného schématu PCB a vytisknutého společnosti JLCPCB na naše vlastní
náklady.

\begin{figure}[h]
	\centering
	\begin{subfigure}[b]{0.4\linewidth}
		
		\caption{Diagram PCB}
	\end{subfigure}
	\begin{subfigure}[b]{0.4\linewidth}
		
		\caption{PlantHub PCB se senzory}
	\end{subfigure}
	\caption{}
\end{figure}

\clearpage

\section{Hlavní program}

\subsection{Postup práce}

Náš hlavní program pro zavlažování a komunikaci s databází a WUI
jsme začali psát ve vysokoúrovňovém programovacím jazyce Python. Od toho jsme
ale nakonec upustili kvůli horší výkonu, a tak jsme program přepsali v programovacím jazyku GO.

\begin{figure}[h]
	\centering
	
	\caption{Vývojový diagram programu}
\end{figure}

\subsection{Fáze programu}

Fáze programu se spouštějí buďto v samostatné go rutině a komunikují spolu
pomocí channelů nebo na základě podmínek kde se po splnění požadavků ukončí.

\subsubsection{Měření}

Senzor vlhkosti půdy a DHT11 průběžně posílají naměřená data do Rpi, kde se
ukládají do databáze. Jestliže naměřené hodnoty překročí limitní hodnoty, Rpi
pošle signál pro otevření tranzistoru což spustí čerpadlo.

\subsubsection{Periodické ukládání dat}

V samostatné rutině běží funkce pro ukládání naměřených dat v periodě 4 hodin.
Naměřená data jsou následně statisticky zobrazena v UI.

\subsubsection{Controller}

Po spuštění měřící sekvence a sekvence periodického ukládání dat se spustí
buďto incializační sekvence a nebo zavlažovací sekvence podle toho jestli jsou
v databázi data nastavení, nastavovaná ve WUI. Pokud data nejsou tak program
čeká na uložení dat z WUI a LED dioda bliká dvakrát po sobě dokud data nejsou
dostupná, pokud ano spustí se zavlažovací sekvence, načtou se limitní data z
databáze a v periodě 1 sekundy se budou číst data o vlhkosti půdy.

\subsubsection{Inicializace}

Půda musí být ze začátku suchá. Senzor vlhkosti půdy zasuneme co nejhlouběji do
půdy. Rpi bude chvíli sbírat data a pak je zprůměruje do hodnoty, která bude
sloužit jako limit pro spuštění čerpadla.

V UI jde navíc ještě manuálně nastavit hranice vlhkosti půdy pro spuštění
čerpadla.

Nastavit se dá také množství vody, které bude přečerpáno při jednom spuštění a
jaká je hranice pro přijatelnou výšku hladiny vody v nádrži. Pokud nejsou tyto
hodnoty uvedeny čerpadlo bude vodu přečerpávat, dokud se nezmění hodnota
kapacitního čidla pro měření vlhkosti půdy a HC-SR04 použije výchozí nastavení.

\subsubsection{Zavlažování}

Čerpadlo začne čerpat vodu a zavlažovat rostlinu. Voda se čerpá tak dlouho,
dokud senzor vlhkosti půdy nezmění svou hodnotu nebo dokud není vyčerpán limit
přečerpané vody na jedno spuštění.

\subsubsection{Kontrola}

Po ukončení přečerpávání se spustí HC-SR04 a změří výšku hladiny vody. Naměřená
data poté odešle do Rpi kde se uloží do databáze. Pokud bude naměřená hodnota
nižší, než je limitní hodnota, začne blikat LED dioda a Rpi odešle upozornění o
doplnění nádrže do UI. Jakmile bude hladina doplněna, signalizace se vypne.

\subsubsection{Ukládání dat}

Náš systém ukládá zvlášť periodicky naměřená data a data naměřená před
zavlažováním, dále ukládá nastavení jak pro limity k zavlažování, tak pro
WUI.

\section{WUI}

Webovovou aplikaci jsme napsali pomocí javascriptového frameworku
React.js, CSS frameworku
Tailwind a programovacího jazyku Typescript, který je supersetem javascriptu,
podporujícím volitelné statické typování. Ve webovém rozhraní je možné zobrazit
si statisky jak živě
naměřených dat, tak dat uložených v databázi. Z OpenWeather API získáváme data
o předpovědi počasí a do dahsboardu renderujeme předpovědi na dalších 15H.

\begin{figure}[h]
	\centering
	
	\caption{Okno prvotního nastavení. Nastaví se zde limity a celkové
		nastavení aplikace.}
\end{figure}

\begin{figure}[h]
	\centering
	
	\caption{Dashborad WUI}
\end{figure}

\begin{figure}[h]
	\centering
	
	\caption{Interaktivní ovládání celého systému lze provést v již
		zmiňované webové aplikaci. Dovoluje uživateli kdykoliv spustit
		čerpadlo na
		zalévání rostliny.}
\end{figure}

\begin{figure}[h]
	\centering
	
	\caption{V nastavení se dá změnit nastavení aplikace i limitů pro
		zavlažování. Nastavení se poté uloží do databáze.}
\end{figure}

\clearpage

\section{Databáze}

Pro databázi jsme se rozhodli použít databázový systém PostgreSQL. Jak vyplývá
z názvu, jedná se o SQL databázi, ty jsou vhodné pro ukládání velkého objemu
dat, jako právě data z našich senzorů. Webová aplikace používá pro přístup k
datům z databáze GraphQL API.

GraphQL je query, který je konkurent řešení REST API. Nabízí rychlejší
tvorbu API a také umožňuje efektivnější přístup k datům z databáze. Umožňuje
vybrat pouze data, která momentálně aplikace používá a dovoluje vynechat data,
která zrovna potřebné nejsou.

\begin{figure}[h]
	\centering
	
	\caption{Schéma databáze}
\end{figure}

\section{Webový server}

Web server jsme napsali v moderním jazyku Go, který nyní roste v popularitě
hlavně mezi cloudovými vývojáři a v oblasti vývoje microservices. Dokáže se
exekuční rychlostí přiblížit k nízkoúrovňovým jazykům jako je C nebo Rust, ale
zároveň zůstává velmi lidsky čitelný a jednoduchý na použití. Na rozdíl od
jazyků jako C a Rust má například garbage collector.

\subsection{Go}

Go je open-source programovací jazyk, který byl vytvořen společností Google v roce 2009. Je to stále relativně nový programovací jazyk, který se nevyvinul z jiných jazyků jako C\# a Java. Go ignoruje teorii o programovacích jazycích. Místo toho aby se zaměřoval na akademické teorie, se zaměřuje na reálné praktiky používané pro vývoj next-gen v cloudových, distribuovaných a souběžných aplikacích.

Jazyk Go je staticky typovaný a využívá garbage collector, jedná se o kompilovaný programovací jazyk, který své binární soubory kompiluje pro každou platformu. Dá se zařadit do skupiny C jazyků na základě jeho základního syntaxe. Go poskytuje expresivní syntax s jednoduchým typovým systémem a má vestavěné nástroje pro paralelní programování. Výkon Go je srovnatelný s jazyky C a C++, ale zároveň nabízí rychlý a jednoduchý vývoj aplikací.

Stejně jako C a C++ se Go kompiluje do nativního strojového kódu, takže nepotřebujeme běhové prostředí jako CLR a JVM. To má řadu výhod, třeba při distribuci aplikace v aplikačních kontejnerech jako je Docker.

\subsubsection{Paralelní programování v Go}

Vývoj počítačů se značně posunul v průběhu posledního desetiletí. V minulosti aplikace běžely na počítačích pouze s jediným procesorovým jádrem. Dnes je standardní vidět čtyř-jádrové procesory v uživatelských počítačích, dokonce i naše Raspberry má dvě jádra. Stále ale používáme programovací jazyky a technologie navržené v éře, kdy byly dostupné pouze jednojádrové procesory.

Většina programovacích jazyků dnes nabízí knihovny nebo frameworky pro paralelní programování, ale nemají tuto vlastnost zbudovanou přímo v jádře jazyka. V Go je paralelní programování součástí jazyka už od samotného počátku. Používá takzvané Gorutiny, které umožňují spouštět funkce souběžně. Souběžné funkce pak mezi sebou mohou komunikovat a předávat data pomocí kanálů. Dokonce i některé standardní knihovny jazyka mají zabudovanou souběžnost. Například standardní knihovna 'net/http' pro programování HTTP zpracovává přicházející požadavky souběžně pomocí Gorutin.

\subsubsection{Typový systém}

Pragmatický design Go neobsahuje klíčové slovo pro třídu a jeho objektová orientace je odlišná od tradičních objektově orientovaných programovacích jazyků. V Go nahrazuje funkci tradiční třídy typ struct. Dědění není v go podporováno, ale podporuje kompozici typů.

Zde je příklad, který demonstruje typový systém Go spolu s rozhraním (interface), typem struct a vnořením pro typovou kompozici.

\begin{figure}[h]
	\centering
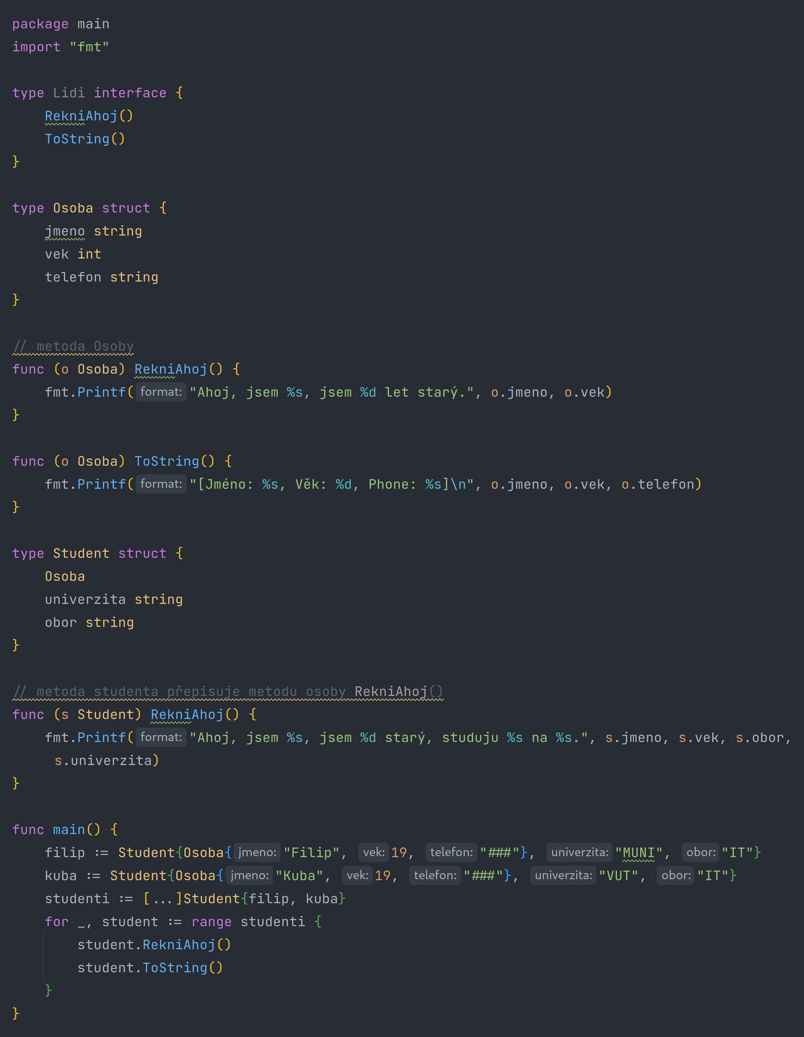
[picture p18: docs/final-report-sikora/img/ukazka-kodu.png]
	
	\caption{Ukázka typového systému}
\end{figure}

\clearpage

\section{Závěr}

Náš projekt je stále ve vývoji a mnoho z kritických funkcí projektu není ještě dokončeno. S vývojem dále pokračujeme, protože se jedná o naši maturitní práci. Myslíme si, ale že tento projekt má v budoucnu potenciál stát se úspěšným startupem, takže plánujeme pokračovat ve vývoji i po maturitě.

Tato práce byla pro nás velkým přínosem, naučili jsme se mnoho nových dovedností a načerpali nové informace.

\clearpage

\section{Seznam zkratek a pojmů}

\begin{acronym}
	\acro{WUI}{Webové uživatelské rozhraní}
	\acro{API}{Application programming interface}
	\acro{REST}{Representaion programming interface}
	\acro{GraphQL}{Graph query languge}
	\acro{PCB}{Printed circuit board}
	\acro{RPi}{Raspberry Pi}
	\acro{ARM}{Advanced RISC Machines}
	\acro{GPIO}{General-purpose input/output}
	\acro{DHT11}{Digital humidity temperature (sensor) v.11}
	\acro{HC-SR04}{Ultrasonický senzor vzdálenosti}
	\acro{MCP3008}{Analog-digital converter}
	\acro{Cerpadlo}{Ponorné mini čerpadlo eses}
	\acro{2N2222}{NPN tranzitor}
	\acro{SPI}{Serial peripheral interface}
	\acro{SAR}{Successive-approximation}
\end{acronym}

\clearpage

\section{Použité nástroje}

\begin{acronym}
	\acro{Code-OSS}{Open-source verze známého textového editoru Visual
		Studio Code.}
	\acro{GoLand}{Inteligentní IDE vyvinuté společností
		JetBrains speciálně pro jazyk Go.}
	\acro{Git}{Software pro tracking změn souborů repozitáře projektu
		uloženého na GitHubu.}
	\acro{Figma}{Webová aplikace pro tvoření vektorové grafiky a návrhů
		uživatelských rozhraní.}
	\acro{FreeCad}{Open-source program pro modelování 3D objektů.}
	\acro{EasyEDA}{Webová aplikace nabízející jednoduché
		prostředky pro návrh technických
		schémat}
\end{acronym}

\section{Použité zdroje}

\begin{itemize}
	\item \href{http://www.latex-tutorial.com}{LaTeX-Tutorial}.
	\item \href{http://www.freecodecamp.org}{Free Code Camp}.
	\item \href{http://www.go.dev}{Go lang}.
	\item \href{http://www.reactjs.org}{React.js}.
	\item \href{http://www.tailwindcss.com}{Tailwind CSS}.
	\item \href{http://www.typescriptlang.org}{Typescript}.
	\item \href{https://www.kali.org/tools/code-oss}{Code-OSS}.
	\item \href{https://www.jetbrains.com/go/}{Goland}.
	\item \href{https://git-scm.com/}{Git}.
	\item \href{https://www.figma.com/}{Figma}.
	\item \href{https://www.freecadweb.org/}{FreeCad}.
	\item \href{https://componentsearchengine.com/library/easyeda}{EasyEDA}.
\end{itemize}

\listoffigures

\section{Seznam příloh}

\begin{itemize}
	\item \href{https://github.com/POJFM/dmp-plant-hub}{Zdrojový kód na github.com}
	\item Prezentace
	\item \href{https://www.youtube.com/watch?v=oo2_pDX5OE4}{Videoprezentace}
\end{itemize}

\end{document}

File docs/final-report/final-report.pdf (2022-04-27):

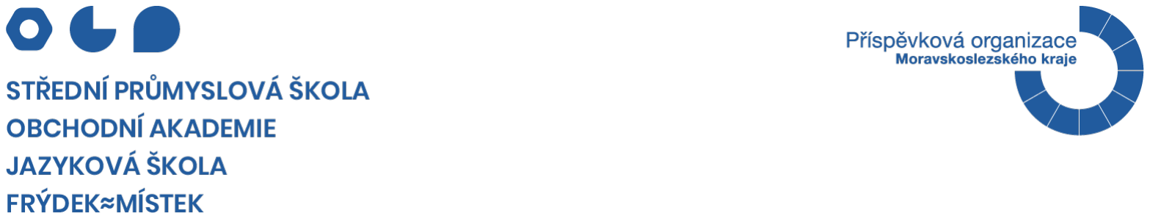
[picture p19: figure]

## MATURITNÍ ZKOUŠKA

PRAKTICKÁ ZKOUŠKA Z ODBORNÝCH PŘEDMĚTŮ

## Zavlažovací systém PlantHub

## Téma č. 4

Obor vzdělání: 18 – 20 – M/01 Informační technologie

Informační technologie

Třída: | 4. IT | Autor práce: | Jakub Vantuch, Filip Sikora
Školní rok: | 2021/22 | Vedoucí učitel práce: Ing. Jiří Sumbal
| | Oponent práce: | Ing. Beňová Jiřina

## Prohlášení autora

„Prohlašujeme, že jsme tuto práci vypracovali samostatně a použili jsme literárních pra‐

menů a informací, které citujeme a uvádíme v seznamu použité literatury a dalších zdrojů

informací.“

Ve Frýdku‐Místku, dne: | | | | | podpis
Ve Frýdku‐Místku, dne: | | | | | podpis

## Zadání práce

Jakub Vantuch

- Hardwarové řešení ‐ stanovení cílů, volba hardware (řídící jednotka, senzory, akční

členy)

- Návrh obvodu a plošného spoje
- Fyzická realizace
- Naprogramování řídící jednotky
- Interaktivní ovládání PlantHubu z webového UI
- Odladění, ověření funkčnosti

Filip Sikora

- Softwarové řešení ‐ stanovení cílů, volba sw platformy a konkrétního software
- Konfigurace RPi jako webového serveru
- Vytvoření databáze
- Vytvoření front end
- Vytvoření back end
- Nastavení bezpečnosti
- Interaktivní ovládání PlantHubu z webového UI
- Odladění, ověření funkčnosti

## Anotace

PlantHub je zavlažovací systém, s plánovaným a automatickým způsobem zavlažování.

Nastavení celého systému je možno upravit přes webové uživatelské rozhraní (WUI), které

navíc nabízí i dashboard a prostředí pro manuální ovládání čerpadla. Jádrem našeho systému

je mikropočítač Raspberry Pi (RPi), který slouží jako hostovací zařízení pro webový server, da‐

tabázi, a zároveň jako řídící jednotka celého našeho systému. Systém PlantHub dále získává

informace o vlhkosti půdy, teplotě, vlhkosti vzduchu, hladině vody a vykresluje je ve svém

WUI. Ve stejné chvíli naměřená data ukládá do databáze v periodě 4 hodin. Jelikož voda ča‐

sem v nádrži dojde, systém PlantHub snímá stav hladiny vody v nádrži a včas upozorní, že je

třeba ji doplnit.

## Klíčová slova

zavlažování; automatizace; statistika; mikropočítač; uživatelské rozhraní

## Obsah

1 | Úvod | 7
2 Seznam zkratek a pojmů | 8
3 Hardware | 10
4 Návrh obvodu a plošného spoje | 14
5 Fyzická realizace | 16
6 Hlavní program | 20

7 WUI | 24
8 Databáze | 29
9 Webový server | 30
10 Docker a kontejnerizace | 31
11 Bezpečnost | 33
12 Závěr | 34
13 Seznam obrázků | 35
14 Reference | 36

15 Seznam použitého softwaru | 37
16 Seznam příloh | 38

## 1 Úvod

Naším cílem je návrh, sestavení a naprogramování automatického zavlažovacího sys‐

tému s názvem PlantHub. Systém se skládá z řídící jednotky (stanice), senzorů, čerpadla,

nádrže a WUI. Tato stanice pravidelně snímá data ze senzorů měřících teplotu a vlhkost

vzduchu, vlhkost půdy a stav hladiny v nádrži, ze které stanice přečerpává vodu. Naměřená

data se živě odesílají a zobrazují ve WUI, ve stejné chvíli se samostatně, v periodě čtyř hodin

ukládají do databáze. Přístup k naměřeným datům a WUI má pouze uživatel lokální sítě, do

které je PlantHub připojen.

WUI je hostované na naší stanici. Uživatel má možnost zobrazení statistik jak živě na‐

měřených dat, tak dat historických. WUI také nabízí manuální kontrolu nad čerpadlem, na‐

stavením WUI a samotné řídící jednotky.

Jednotlivé součásti a moduly stanice jsme vybrali podle finanční dostupnosti a adekvát‐

ních technických požadavků na přesnost měření. Obvod jsme v testovací verzi postavili na

nepájivém poli a ve finální verzi navrhli a objednali vlastní plošný spoj (PCB). Pro ochranu

naší stanice jsme navrhli kryt, který jsme následně vytiskli na 3D tiskárně.

Hlavní program jsme napsali v programovacím jazyce Go, jehož hlavní využití je vytvá‐

ření backendů webových aplikací. Tento jazyk se nám zalíbil natolik, že jsme se v něm roz‐

hodli vytvořit jak application programming interface (API), databázové funkce, tak i hlavní

program. Program je rozdělen na několik sekvencí, z toho hlavní jsou měřící sekvence a sek‐

vence controlleru, která pomocí snímání dat z databáze určuje, zda se jedná o první spuštění

PlantHubu. Na základě toho určí, jestli se spustí incializační sekvence nebo sekvence samot‐

ného zavlažování.

- Kapitoly 1, 2, 12, 13, 14, 15, 16 jsme zpracovali společně.
- Kapitoly 3, 4, 5, 6 zpracoval Jakub Vantuch.
- Kapitoly 7, 8, 9, 10, 11 zpracoval Filip Sikora.
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

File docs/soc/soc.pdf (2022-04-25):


# Zavlažovací systém PlantHub

## Filip Sikora, Jakub Vantuch

## soutěž SOČ 2022

Třída: 4.IT | Školní rok: 2021/22

## Prohlášení

Prohlašuji, že jsem svou práci SOČ vypracoval/a samostatně a použil/a jsem pouze pra-

meny a literaturu uvedené v seznamu bibliografických záznamů.
Prohlašuji, že tištěná verze a elektronická verze soutěžní práce SOČ jsou shodné.

Nemám závažný důvod proti zpřístupňování této práce v souladu se zákonem č. 121/2000 Sb., o právu autorském, o právech souvisejících s právem autorským a o změně některých zákonů (autorský zákon) ve znění pozdějších předpisů.

Ve Frýdku-Místku dne 4. 3. 2022

## Prohlášení

Prohlašuji, že jsem svou práci SOČ vypracoval/a samostatně a použil/a jsem pouze pra-

meny a literaturu uvedené v seznamu bibliografických záznamů.
Prohlašuji, že tištěná verze a elektronická verze soutěžní práce SOČ jsou shodné.

Nemám závažný důvod proti zpřístupňování této práce v souladu se zákonem č. 121/2000 Sb., o právu autorském, o právech souvisejících s právem autorským a o změně některých zákonů (autorský zákon) ve znění pozdějších předpisů.

Ve Frýdku-Místku dne 4. 3. 2022
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

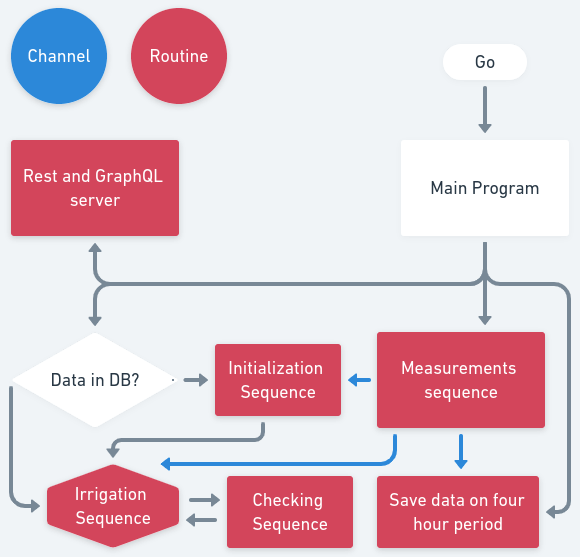
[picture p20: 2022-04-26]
docs/final-report/img/go.png

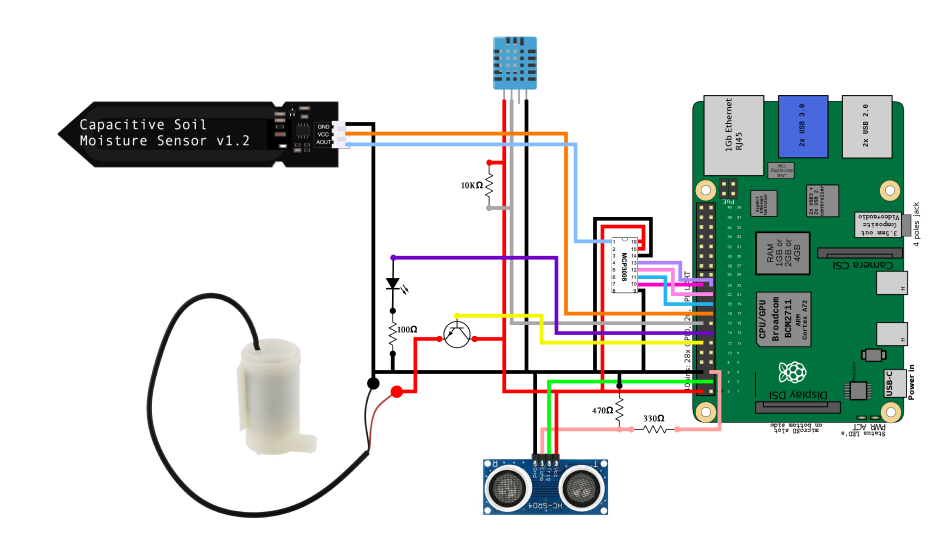
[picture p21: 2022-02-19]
docs/final-report-sikora/img/obvod.png

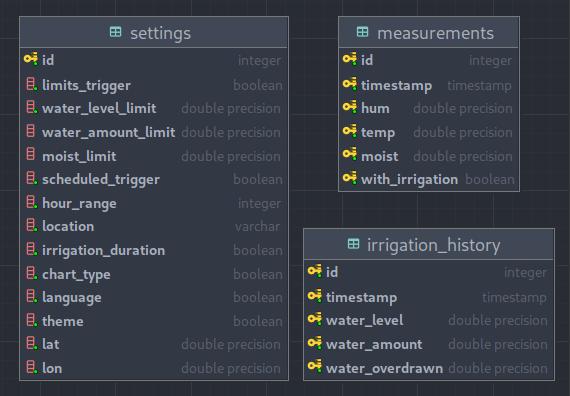
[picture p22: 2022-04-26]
docs/final-report/img/db.png

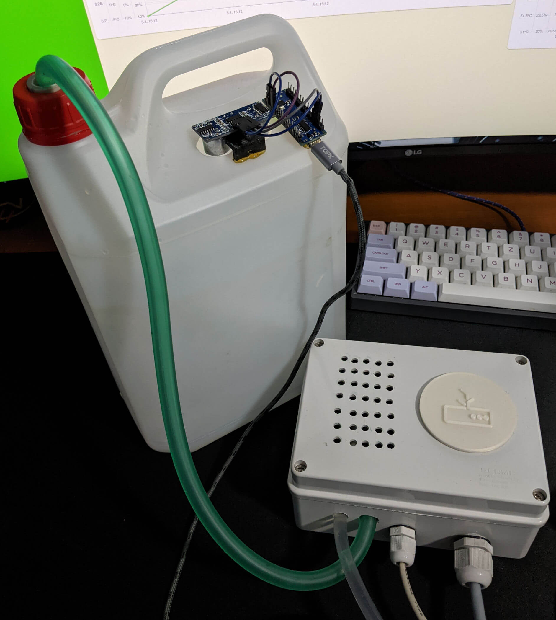
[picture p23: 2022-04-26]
docs/final-report/img/nadrz.jpg

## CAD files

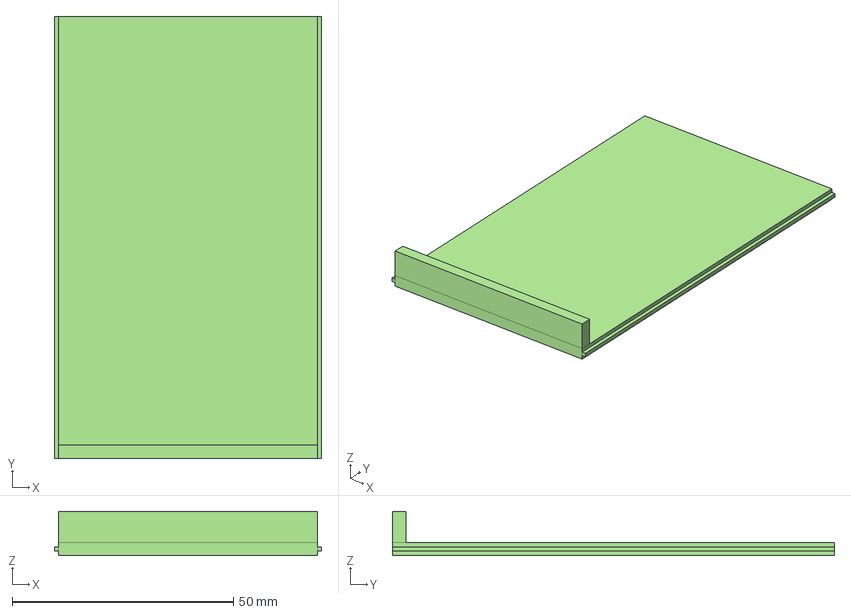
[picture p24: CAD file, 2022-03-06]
case/bottom-part/bottom-part.FCStd
60.5 x 100.0 x 10.0 mm

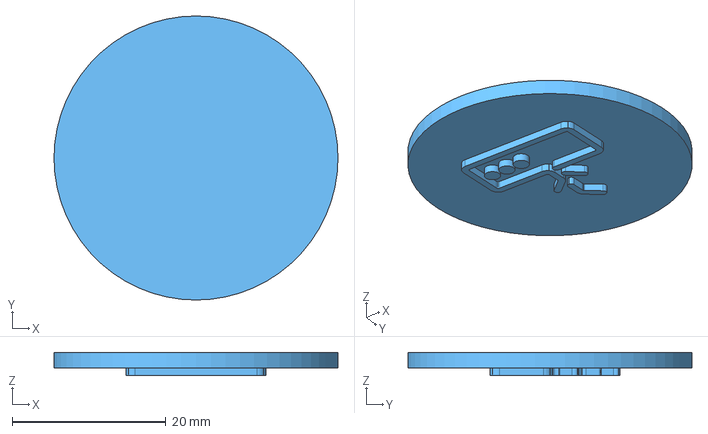
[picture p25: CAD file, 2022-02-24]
case/logo/logo.FCStd
37.0 x 37.0 x 3.00 mm

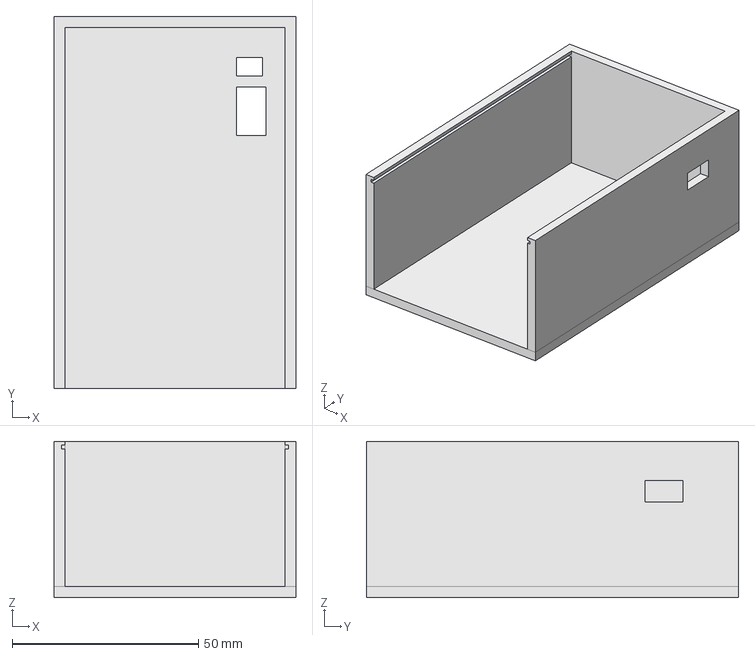
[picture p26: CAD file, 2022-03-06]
case/top-part-fix.FCStd
65.0 x 100.0 x 42.0 mm

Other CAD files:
case/top-part-fix/top-part-fix-Body.stl
case/bottom-part/bottom-part-Body.stl
case/logo/logo-Body.stl

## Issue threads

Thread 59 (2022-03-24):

minor fixes

TurniXXD, 2022-03-24:
- [x] init form load init measured
- [x] init form button active state is fucked
- [x] init form active state from DB data
- [x] gql mutation

Closed 2022-04-01.

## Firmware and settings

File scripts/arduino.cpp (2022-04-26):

#include <Arduino.h>

const int trigPin = 9;
const int echoPin = 10;
float duration, distance;

void setup() {
  pinMode(trigPin, OUTPUT);
  pinMode(echoPin, INPUT);
  Serial.begin(9600);
}

void loop() {
  digitalWrite(trigPin, LOW);
  delayMicroseconds(2);
  digitalWrite(trigPin, HIGH);
  delayMicroseconds(10);
  digitalWrite(trigPin, LOW);
  duration = pulseIn(echoPin, HIGH);
  distance = (duration*.0343)/2;
  Serial.println(distance);
  delay(100);
}

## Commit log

2021-06-11 ⚙ funkcionalita
2021-06-15 🐍 python-circuit-program-v1
2021-06-19 🐍 py-program-logic-update
2021-11-06 circuit img
2021-11-18 :tada: ALL SORTS OF THINGS
    [Gerber_BoardOutline.GKO, Gerber_BottomLayer.GBL, Gerber_BottomSolderMaskLayer.GBS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]
2021-11-25 :construction: sensors + dht lib
2021-11-25 📝 .gitignore
2021-11-25 ⚙️ run.sh script
2021-11-25 📖 readme
2021-11-25 ⚙️ server port
2021-11-25 🔥 burn legacy python shite
2021-12-19 💩 don't look at this
2021-12-30 irrigation duration action buttons state
2022-02-17 adc algo test and kyberstoc report
2022-02-19 🍫 říkej mi LaTeX master
2022-02-19 📖 parindent
2022-02-22 3D model of case
    [bottom-part-Body.stl, bottom-part.FCStd, logo-Body.stl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]
2022-02-24 sensors finally working
2022-03-04 fix case
    [bottom-part-Body.stl, bottom-part.FCStd, top-part-Body.stl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]
2022-03-24 LED and PUMP
2022-03-24 go diodes, sensors on client
2022-03-25 fuck diodes, subnet man in readme
2022-03-26 pump state with check seq and moist range
2022-03-26 🐋 dockerino
2022-04-10 🐋 pls work already i beg you
2022-04-15 filter bad data + move moist percentage calculation
2022-04-16 🧹 stuff
2022-04-18 🔧 opravy
2022-04-18 🐸 fml
2022-04-19 🫐 UpdateSettings() in go fixed
2022-04-19 🫐 UpdateSettings() JS
2022-04-19 🫐 hcsr arduino
2022-04-26 🫐 hcsr arduino code
2022-04-26 🗒️ new readme ✨
2022-04-26 ✨ new img + compress
2022-04-26 🔧 sort out .env stuff
2022-04-26 🪲 sum čárky
2022-04-26 ✅ make code politically correct
2022-04-26 🪲 fix pump + moisture
2022-04-27 🤡 undo jakub vantuch
2022-04-27 🚑 redo Filip Sikora
2022-05-11 🧠 funguj
2022-05-11 🤦‍ fix irrigation timestamp
2022-05-11 ⛑‍ add default_water_amount to DB
2022-05-11 🐳‍ add /dev/ttyUSB0
2022-05-12 🙏 pls
2022-05-16 🙏 final fixes (hopefully)
2022-05-16 ✍ fix waterLevel in sequences.go
2022-05-23 📓 add docs
